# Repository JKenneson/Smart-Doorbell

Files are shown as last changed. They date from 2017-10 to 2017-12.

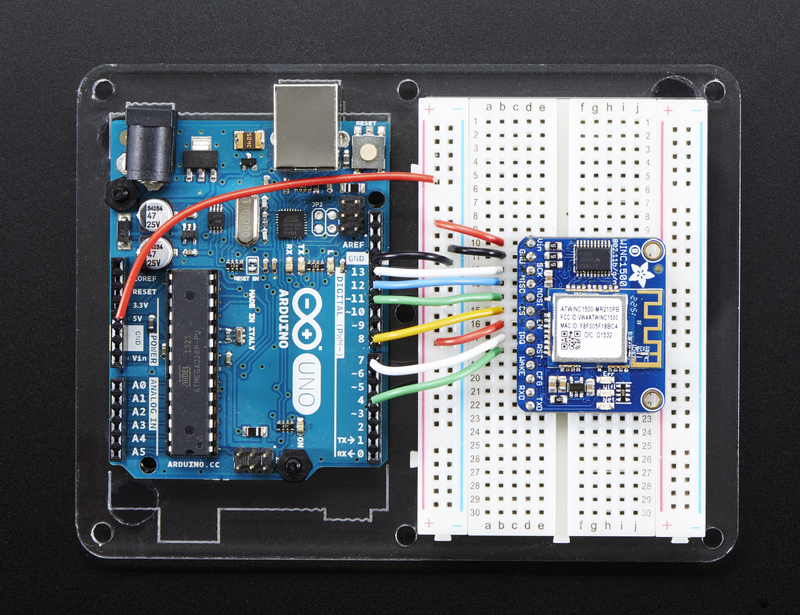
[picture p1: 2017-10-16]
Arduino Testing/Wifi_Test/adafruit_products_2999_top_demo_ORIG.jpg

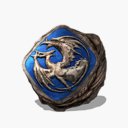
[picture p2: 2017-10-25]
Arduino Testing/Camera_Test/test_jpg.jpg

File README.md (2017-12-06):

# Senior Design ECE 1896
KFM Industries
Jonathan Kenneson, Alexander Furches, and Kyle Monto
Smart Doorbell

The following upper level directories can be found in the current directory:
* Arduino Testing
* Bluemix
* Eagle
* Checkoffs
* Libraries
* Solidworks

Each of the corresponding directories contains parts of the design project needed to recreate the final prototype.

The parts needed to recreate the prototype include:
* Arduino MEGA
* TTL Serial JPEG camera (Adafruit)
* PIR Motion Sensor
* ATWINC1500 Wifi breakout

The Arduino Testing directory contains files related to testing individual components and combinations of components.

The Bluemix directory contains code that can be imported in order to recreate the Node-RED setup associated with the project.

The Checkoff directory contains the code used during the checkoff demonstrations.

The Eagle directory contains all relevant files associated with development of the custom shield placed on top of the Arduino MEGA.

The Libraries directory contains the files associated with the libraries needed to run the Arduino code on the Arduino MEGA.

The Solidworks directory contains all files associated with the development of the 3D enclosure printed to house the final prototype.

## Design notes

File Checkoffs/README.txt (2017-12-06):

This folder contains all our Arduino code for each of the 3 demos during the course of this project.

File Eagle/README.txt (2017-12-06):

This directory contains 3 subdirectories.

Boards - Contains the boards associated with the Arduino Mega and ATmega1284 MCP, and the final shield for the Arduino Mega.

Final Design Folder - Contains design files needed in order to have the custom components professionally printed.

Schematics - Contains the schematics for each of the MCPs examined as well as the Shield schematic that was ultimately choosen.

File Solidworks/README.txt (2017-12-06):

The Solidworks directory contains 2 subdirectories.

Part Files - contains the files that can be view and edited in Solidworks.

STL Files - contains the files that are needed in order to 3D print the components for the final prototype.

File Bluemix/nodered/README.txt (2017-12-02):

Mainflow.json is the only file to be concerned in this directory to get working.

With IBM Cloud/Bluemix, create a Node-RED project.
Within the Node-RED visual editor, copy the entire mainFlow.json text, and select import -> clipboard.
Paste the text into the clipboard and import the flow.

Some things to be concerned with that may require further setup.

Visual recognition node requires API key in order to operate. This can be set up within IBM Cloud by searching for the Visual Recognition service and linking it to the Node-RED project.

The email notification with need an account and password in order to send an email.

Cloudant DB will need permissions adjusted so the database can be read from an unknown user. This is found under Cloudant permissions.

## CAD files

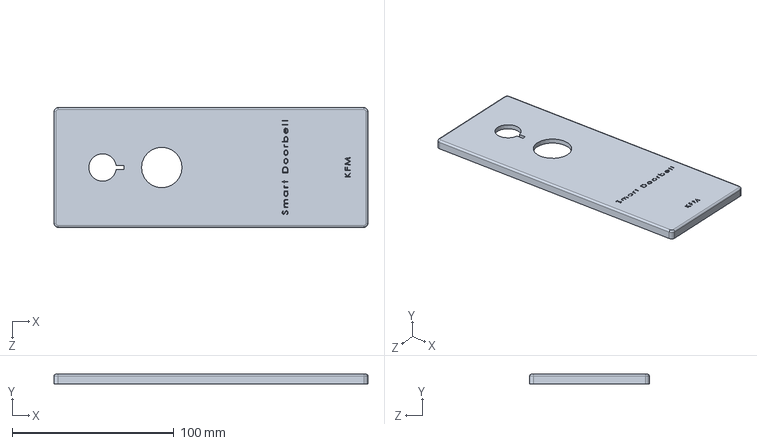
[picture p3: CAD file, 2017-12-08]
Solidworks/Part Files/top_KFM-v2.SLDPRT
194.0 x 6.00 x 74.0 mm

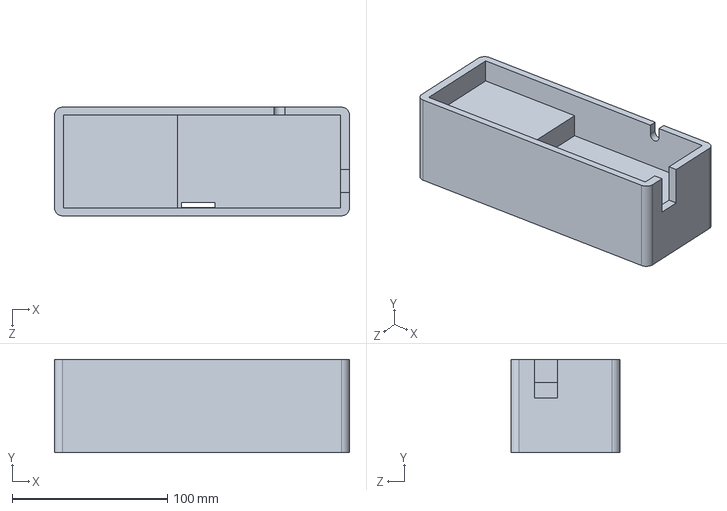
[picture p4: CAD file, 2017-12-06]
Solidworks/Part Files/Bottom_KFM.SLDPRT
190.0 x 60.0 x 70.0 mm

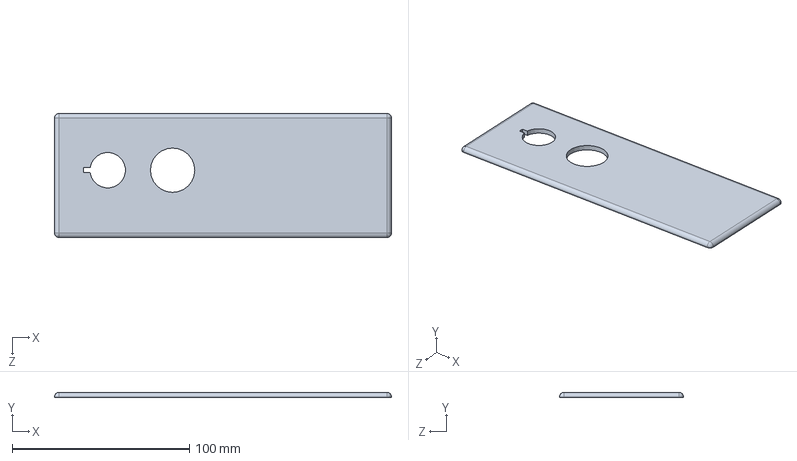
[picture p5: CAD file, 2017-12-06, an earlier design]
Solidworks/Part Files/top_KFM.SLDPRT
190.0 x 3.00 x 70.0 mm

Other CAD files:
Solidworks/STL Files/Bottom_KFM.STL
Solidworks/STL Files/top_KFM-v2.STL
Solidworks/STL Files/top_KFM.STL

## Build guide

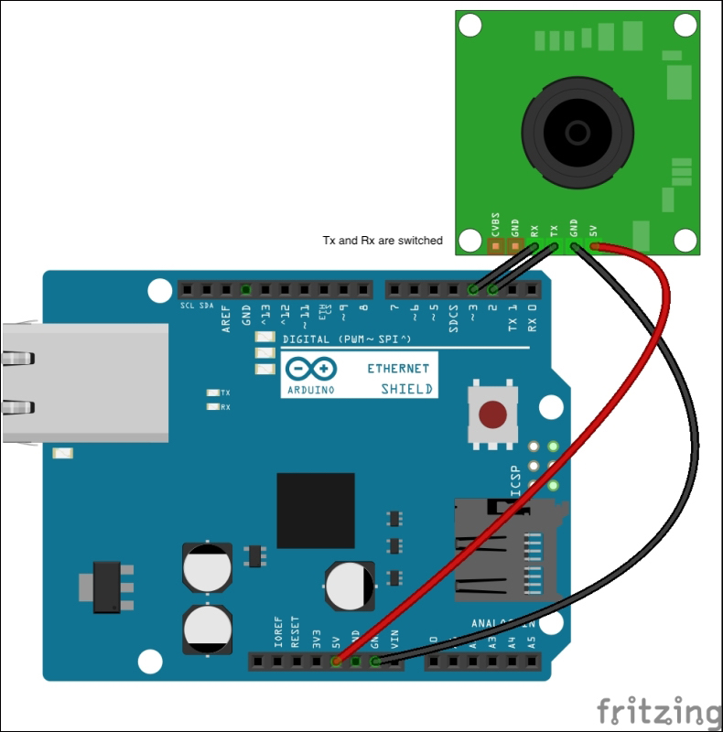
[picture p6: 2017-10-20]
Arduino Testing/Camera_Test/Camera_WIring_reference.jpg

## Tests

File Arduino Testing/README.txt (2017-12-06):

This folder contains all our Arduino testing files for our sub-component testing on the embedded system.

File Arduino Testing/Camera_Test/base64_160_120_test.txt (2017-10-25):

/9j//gAAAAAAAAAAAAAAAAAAAAAAAAAAAAAAAAAAAAA=EgtRBFEEAAAAAAAAAAAAAAAAAAAAAAAAAAAAAAAAAAA=BgYMCQkHCg8NDw8ODQ4OEBIXFBARFhEODhQbFBYYGRo=GhoQExweHBkeFxkaGQEEBQUGBQYMBwcMGREOERkZGRk=GRkZGRkZGRkZGRkZGRkZGRkZGRkZGRkZGRkZGRkZGRk=GRkZGRkZGRkZGRkZGRn//gAAAAAAAAAAAAAAAAAAAAA=IQAAAAAAAAAAAAAAAAAAAAAAAAAAAAAAAAAAAAAAAAA=AwQFBgcICQoLAQAAAAAAAAAAAAAAAAAAAAAAAAAAAAA=BgcICQoLEAAAAAAAAAAAAAAAAAAAAAAAAAAAAAAAAAA=MUEGE1FhByJxFDKBkaEII0KxwRVS0fAkM2JyggkKFhc=GBkaJSYnKCkqNDU2Nzg5OkNERUZHSElKU1RVVldYWVo=Y2RlZmdoaWpzdHV2d3h5eoOEhYaHiImKkpOUlZaXmJk=mqKjpKWmp6ipqrKztLW2t7i5usLDxMXGx8jJytLT1NU=1tfY2drh4uPk5ebn6Onq8fLz9PX29/j5+hEAAAAAAAA=AwQHBQQEAAAAAAAAAAAAAAAAAAAAAAAAAAAAAAAAAAA=QpGhscEJIzNS8BVictEKFiQ04SXxFxgZGiYnKCkqNTY=Nzg5OkNERUZHSElKU1RVVldYWVpjZGVmZ2hpanN0dXY=d3h5eoKDhIWGh4iJipKTlJWWl5iZmqKjpKWmp6ipqrI=s7S1tre4ubrCw8TFxsfIycrS09TV1tfY2dri4+Tl5uc=6Onq8vP09fb3+Pn6/90AAAAAAAAAAAAAAAAAAAAAAAA=z8nHVsjrzShm9cfjXzlnaw+o8Mc8k5qG506G7IMm5JA=fdkQkMv4ikk07jvZnJ+IfBst6vmwt5zqPmcDD465IA8=m/CvPr7TbnT5Atzl16hl6Y/pXTCSkdNOa2IYzgAAAAA=pU6TGMAgllx68iul3Nyys3n8ggJ061DIhTDRsTCeT6g=+lW1fchDfODD5PmUdDTWLqRtbI9Ox+lRZ9TS5ainJGE=mI55JHT8PyroPD9nZ30kn2u/NnMq7lUgkz+wx0H61vQ=VeSTIm2kd5pmpCzYWmnQiBw4yoVHmUj03/uwTj7zKT8=lW5dWEd3A5jma3uolG/yEluZYRjH7+VzhCO67QhHRhw=V7EYqUbdEefJ2Ziwa9aaVIqrAk10gYTXdwVkXGesQB0=o+oJxk8mtj7JfX9ul3c20kMEig29zqFwYEUf3o1O0uM=vvRDjrnNKLlNcsVt/WoPTVmYJtMtL25fXrp9VvJDkSg=kdll9cu3U/nmtC48TCWw8qy05bWJwcTzyrbwFfYnDM0=jt5j/wAAAAAAAAAAAAAAAAAAAAAAAAAAAAAAAAAAAAA=GMa46bQx+Zhg45/LpWSPFtzbknT/AAAAAAAAAAAAAAA=IB9xivKq4mTfu6+f+R1xor7RhTXkrtvkkeUsSWd2zyc=qaYJpOAMkY6g1wScpXbOiOhJvMXzAnb/AAAAAAAAAAA=/t0K6VfSlriJcxMTkyJ7+44/DFctaEpRMa21z0ktgls=kowwwPpUOnStZTfYJGPlkFrZyeq91/D+X0ry2ro50zQ=tzZOGPPvSF2GfmbPbFSnqJhubgEkY9TTgzA9T+dMQ4k=Oc7mJqIv7t9aLCInJzjcc9+etREtn7xI7VVmHQa2Tnk=Pp1qJi2epxj1qrAQSE/3iPx6VWcnP3j71SVkK5//0Ms=DnFSKc8kY+tfNNNIZKD0I9PypwbPUigBwPPvUN5ptlo=tGY9RhDEjh14I/Gi9tik3F3PO/Efw4vdNSS60djfW44=q4xIo9cdD/niuISUb8HKsp5BHI/CuyE+dHXCSkiYSbg=7ovkzyR1zUqS7yAFJYdS3b/61dCel+pViRrZjht2W7g=HT8aTcQpx8oHUd6JXDUYxVPmU8469j9algu5FxjK49Q=7QKV7SuOzaOx0XxPHb2ckM6yTXQG23ljIRQD1DYGXz0=MFgPrxXWi9mvmW21qdYYoPmjs0mWOEA8nYq/Kv4Dr1A=elenSqucfJbnFOFmTQwpdRebZ28lyInP7+Lbb2sRx8o=TK42q3rlRnHWsuTxzBp5kiu0/tTUF+VJUmBgXgYKsQc=djGCOQccNjFa1Kqorm6Exhzu3U5DUfE95fzl5pQgH3I=OIYCDPGPTmsqXUp55N1zM0j9nYli35968adSc27s9CM=CMVoQFmcnfuweDnn9Kch27Q5JX+E1g9SuhKShH86YJA=xYVRgE8EjpU36DYq7gv72TOew5qe0vpNKuorqKUQyRM=Bo3J+4w/z+tKSuQ1eOp9DeCfFtt4s0hLiBlEyfJMgbI=VbH8jW/cQG5h8oEpKp3wuP4GHT8K8iS5ZNHAW7C6N7E=kyAJcRnZKn91h1/+tVvOT1wMVgAAAAAAAAAAAAAAAAA=+uRTGKWGM9TURGMAAAAAAAAAAAAAAAAAAAAAAAAAAAA=849aYTycdKpCK7nOf8KrtnP6mrv2A//Rx1PI54NTK1c=zdnsMkDZI9qcD/8AAAAAAAAAAAAAAAAAAAAAAAAAAAA=cg9RXP8AAAAAAAAAAAAAAAAAAAAAAAAAAAAAAAAAAAA=1LTb3Q7o29/Gyup6EYyPb1qNblWAGdhHQn7wr0076o4=taosxTkYVhk9vf8AAAAAAAAAAAAAAAAAAAAAAAAAAAA=N/r1zQ6+Z82Rx3Jziot1ZY6GTa38TMRxzxWmuqyi2EM=mIndu3lNz/TnIH4DnODxxRzOL0E4ppEN9r13eCP7bcQ=l0Y1xH5jlwo9FHYewqqzyTkM74GOAAAAAAAAAAAAAAA=Ij8wVwFxxwPvU8qvIGMetZdS0+ooL8LkKT0bHWmkDBE=uyeue1KKVgIm1C2s+LmaJPdjyfw61UbWDd/LYWst1n8=i2bV/WrVP7T0RDl0Q6K21S5G2eeKzUdQgLvipF0K2LE=a8kkuWH/AAAAAAAAAAAAAAAAAAAAAAAAAAAAAAAAAAA=LHhL2FQQPL/vgeo6+9fTVndRX1rDcW7q6SIGVgcgg8g=IrzMQrtSOWpHlkNupPsLjUEH7vAS6A7rnh/wz+Vau8E=GQcjt7iuRme4059eT60hPX2pW0EO3EHj8MGmFge/50g=ewxmz9OlRM2O3Iqr9AImf5s9vaoS+Tgnn6U+mhNiJmw=/SoJGGPrVpMZ/9LDDk8//XqRSemf0r5uwyUH3qTJ9qQ=77gODHinZOaNdxjgxzz+lPV2BBU4b1oSAi1bS7HX7fw=jVIlZhkJKFG5Poa8i8VeDLrw6xlKm7sz9yVccfX0NbU=GbjKxvTl0ZzoMifKjCRP7tTRzKpwSxHoRyv+NegndWM=oJ2cEYb8zioHlEXDsCD0z1qLPoAjSyOAAoUep7/SlUM=KcO4ye5oasiiXCdwDjge1KsrIQc49CeM1OrVgbJTLlQ=5PT0+tUpNYtrU7XdS/OMcn/61ChzaIXNYY15e3gxaWQ=wU9HmIWlj0q9u8fbb5kCj5kgXaB/wKm5xpLTVitKRag=dJtLYq0cKs4yQzjeSffNX0mZlwo2Y6j0/AVySlKerZo=K0NhJGPGDubsAAAAAAAAAAAAAAAAAAAAAAAAAAAAAAA=V/s6wlnJHzHYduP97p+te2/DrRdS8PaAlpqh+ZJXMSk=YNsjPIXIPYluK5a8lKHKtzkqtOx1/wAAAAAAAAAAAAA=wEloZLV8mKMgwt/sH+E/Tn9K49epzF3zOM9aTzOSOx4=9HKO4hkx0pN/HPX+VCvYV2xhfJ61E0gB68UNX6BqRGQ=4x+lQmQDuPyqkmDIWlxwDUEj59qtX3Ef/9PnweP/AAA=Tlavm7dSiUP608P6n0qdbDHq+SOcnFShunr/AAAAAAA=jNKpxjBxmmBIPzNP3q6GOZRJE3BVhkGpGcD4m+HwAks=7QAAAAAAAAAAAAAAAAAAAAAAAAAAAAAAAAAAAAAAAAA=uZEflSqAUfj+4f8AAAAAAAAAAAAAAAAAAAAAAAAAAAA=+XlPT0+lBkU/MzZXn2qN7l7aFGXWLe3fZu3nsE+Y0gs=i/vD/o9uIozn55jjH4Vo4qCvMzcm9Iki6TJOwGoXcr4=OSifIp/x7Vet7O2tf+PeEIyjhsZJ+pPNY1KjdktEUoo=W7L0cxckAAAAAAAAAAAAAAAAAAAAAAAAAAAAAAAAAAA=eabpsRC5z9BXT2Hw11q+IeSKO0QgczNjI/3Rk/nWUqg=okymo9Tq9K+GFlHJKNSuZZdjAAAAAAAAAAAAAAAAAAA=7wrpGmNus9OhVz/HIN7H8TmuadTmOSVWUtjeXAIy2PY=UYqQTKpHy5/3uaw1Mr3F8/rzjtgUednnPXrRZAw88js=4zQZT1FSAhm7ZyKabj3pgMabJxng1G0/uKdriImm75o=haXBz1qvJiI3lxnA4x6VSmvYUP7yRQcd2Aq0gR//1OY=g2cEdhTg20k5zXzi1RQ8Mc+1PV6SvuBIHzyacrHIwes=Sab2GSq5PU4NPV/ek7gSBvU4H0p+7PSnZiHrIVbKnHU=rC8TeFbbxFG0keLe/A+WXsx7A/40RbvcqL5Xc8i1bTo=60e6NvqKeU46N/C49Qe9Yl1qVtGNu4M/YAZr04JzSfQ=OttLUrRXN9cE/ZYvJQ9Gk/p3qX+yGZt9/dPJ6op2itE=yUNFqxJOW5ftraC35giUD1xzj69ateYf42x6EYyfYk0=YTcpM0VkiYDeQT+mSa19L8M6rqrKLezmkBH+s27UP/A=I4H61zt21Y+ZR1OtsPhXcSc6nexw85AiXzG9/Qfzrs8=TfAOi2I3G2e8kzndcNwT/ujA/SuSdVy2OeVXsdPbW0c=aII7dI7eMdEiQKB+FWBt7/Mfc5rm3MX3H+bjpkAH0o8=NPXPSiwhRKeaUS8devSiwB5xJ60CfPHcVOiATzsHrQY=fnk/Sqt1Qhpuf7p9e9RG6CdWH0zTsBUl1m2T706fgck=qjL4mtUyFLSfQU1BgZ8/itmOIIgPdjVJ/EV87fKyp/s=oqlFtXCxUn1O7nwHmc/jVJySxLHdVIex/9Xkw+cduO4=amRzkZ5FfPvYY/IPKijcQeCcmp9WMfu+o9jUitwMnvU=PkBIHz9KkRs4zxS6AAAAAAAAAAAAAAAAAAAAAAAAAAA=TxZoX/CSaTJaBYTIeVaUElf90joffp6ivGLnQ/7CuXg=J7VoZh3I6++a7KM5Wcbm9K3UQbjgqdp7470+KMuQAp0=x/EmtLrudPqbln4R1a8HmpZyRxHBLSjaB7jPJH0Fdlo=Z8NYRtbU7xpz/dgHB/Fh/SsKlVLYxlO2iOx0vwzpel4=02llErqch5B5j/mc4/CtxQOMktjsa4m7u7Odtt6kyuA=YA4+lPEp/Oo9RD/MwPrS+b2B6UgAAAAAAAAAAAAAAAA=mwAAAAAAAAAAAAAAAAAAAAAAAAAAAAAAAAAAAAAAAAA=G4FGXxRbqMRB5D6jiqEvii4YfuYlUf7RzT5bDRVl1u8=ZT/rtnH8IHFU2nmmb95I7E+rVVuoC+WTzn8M00rtP9M=NSw1AgdlApAD/hTSuAh9M/rSYHrg0X8wsf/W4wHmno8=XzzRWrJkkUDB5p4fI6elK3UBwIH3eR06U5W4xxk+9TY=QWuPV+hPpUoccA8f0padAAAAAAAAAAAAAAAAAAAAAAA=nbgPr9aiyGODjPOKo6rpFlrUPl38KvgEK+PmX6Gr03Y=NNp3Rz9n8ObCA77i6mucH5U4Tj3PJP4YrptO0aw04D4=yW0UJH8SjLf99HmiU3ItzcjUBUdQGPvzUnm9cVloZjw=SjHXrTllNLTsMcJxjJqTzgOdwqeW+4eQvnjqelHnYIA=Tyew7UWsIjkvY4xmSQKvqTjFUJvEVnFnEgc5/gAAAAA=luFim/ipcYhhJHTLHFUZ/EN5McIyxA/3RzTUF1HYoyU=zPMf3srsfc0zAAAAAAAAAAAAAAAAAAAAAAAAAAAAAAA=XHApwxzxRbsSvMnGMZ6464prjdg0mkihnTGMdqTAwMg=6dahJXuID244pucHB9P1qrKwH//X4UOT1yc07cepr54=eqKHByelSJKfWlqwJhJnB747U/du9SfSjUVx4YLjJpw=HxSd1LQZKrZ6GpFf0OKnW4Dlc5GeKeHOOBz9aT3sMcI=Qg9+KcHwfU0t9wQokIHNPWTsT+dTZ2FsOEpyM5/OniU=zjPH407Nbj3AS9ad5xB5P60WBEcuoRRD97Ko78sOapw=viG3ThGaQ+wqVe6ApS+JJTxDF16Fj0qpJrF7P1lKj/Y=eMVXUZVZnkOXZmPueaBnJGOnNGq2D1JQPlzyTQAAAAA=LPoO4/HPp75p4Byev50aoOuo5Rk4ORT/AAAAAAAAAAA=kEYz60uCTgE5obfUCdfT9aV147n2qW2kwTIiPmOOn0o=MnvmnrsIaeetIRjp/wAAAAAAAAAAAAAAAAAAAAAAAAA=Ch+nXrUobA4OaN0MVXGPf1qQSYHB6UvQB6ze/wAAAAA=fT2o1YEkcvIxnIqQS84NS7sBwcAjk0vmc5559anVgL4=bg07z8kUPuMXzsE5yeOlOEp/h5PtRoF2Ne7SHAmdVzk=6nFVn1y3H3SzkdlFK1h2KcmvSvjyYgvuxzVObULqUYc=lZfYcVVhkPB5znPX3qRcDHyjBp9BddSRgM9OfWkHJpM=tsPqKDinjHTPFTbcW5KMFeP6UmcY4HSjW4x2cn5uM80=OBB/Op1YWHA8ipM8Dr1qeoDgQRzzn2pw6exoYIeG28o=45/SjOeOhqdkHUOQPWjqQT+NCeobCHg+1NPAAAAAAAA=IWh//9Hzs9OP5UZwf/rV4Aw3n2/wpQ5JoAUSU8Sc9f0=KEMcJD+VSCY9emetLTcCRJ8n/wAAAAAAAAAAAAAAAAA=2DjAxS+ccHngijZiENyqAAAAAAAAAAAAAAAAAAAAAAA=DIDrMjZ8mIKB/E1V5NRupGIMxUc528CmrD9SIEsQWww=fU8mpQMjmiyARnJ4HalU5PGOKmQDs/TpTg3uAcelDEM=jJ0OaXdjk4pPuMXdxk07JHTFLugJEyfpj0oB5zjoalM=6jH7iD2xSh+ffH1xQvMH5Ds8gmpM9MdT7VPqHoODdeA=U4Mx69KHoA8ZBxnrSjIz398VLWlxvYceh78UufoKTFs=jWJ78U3NV2JP/9LzluPfFNLEYzXzyV9UUM39+cUxpsE=64z1p2uh2Dz9p5IxS/aBnngj6UW0sJD/AAAAAAAAAAA=4BFJoe47ztoDZ/GkbUYk6yDI7A5os3uJEb6uv/LNGY8=vVd9RuG5VwgI6Cq5bvUexCCZWHmMXJ9TmpQuCMnp3xQ=mh7jieeCTjoBSqvPTpSCxIp54Jx6VJu4Xtmk13FuIG4=flPPal3gkAknPWp5Rjg3GT2pQeetFnbYBS/PNLuwQKU=qgHZznv/AAAAAAAAAAAAAAAAAAAAAAAAAAAAAAAAAAA=0A4PvQwtYkzkc8mn5x7Gly2AcTnr0pQ2OR17UNDJA3M=gnrS7j0zkjjpU2dhC5A5J59BS7uT9OKTXYBoPTOBSZ4=vemkybn/0+EkjVu3WqskRGSOfwr5/qOxVfcM57CqzSk=HGTkelWrN6DIzLz7d6YblFPzSYOPXNVygQtqAU4jBJo=a19OxyvyA+gp8qWrERGVnb52LEepqaHliSSeKqySsMk=P4snqc0/uPes3uPoTxthu+AD1p+7aQG/Kp07j1Hgnj0=u+aUNz39eaNtgsiSNTIVGVGe5PtSlu1RuxiA+hOaX0w=d6G0tWKw4enPWnKcgAdBSe24AAAAAAAAAAAAAAAAAAA=rA9sE1IuKTDQlzletA6D+lTa4DgckegpQe/NDsCJR24=9OXJHGTikLcfz16U4NznJyOvvSe40Ozkd/bNLuORjH4=BoukDQHp83UcUuSOp5pIQnf1Hb3oyT06+9O6Qj//1OE=T2qNugNfPFENwVKOzDJUE9K5ya6bd8vy89xWkBoqtJI=SdSxFR8DIrZa6C3F28j3x9ambGcentUrQegqL8w9fpU=YiXHQnAxUtu4aEhOKev3h1HbgVG+49iVCMkjC08+p44=f8mkPQUN6kD8KeDg5NLcNhwbGBnrTgcn5vpU2ewaCjI=zDIGPWncbsDp60nZqwPcAAAAAAAAAAAAAAAAAAAAAAA=9qQH5v8AAAAAAAAAAAAAAAAAAAAAAAAAAAAAAAAAAAA=JBg47/hQOCO9G4iQdPTPQVZQZQHIqHoNCk8YPX3FR4E=njBBpvQQ8cZ6AAAAAAAAAAAAAAAAAAAAAAAAAAAAAAA=wM4I/Wmknv1+lGiEf//V4Vh2HFRMeDjrXz9iilqLlLY=bHf5a5w4xn1rWCurCI93IKtg/wAAAAAAAAAAAAAAAAA=Mke/Sps2h7D4yeucVMGJ4XAH86loPMfnptp6dSDx3+k=U2Y9CZT03Dpk0rNk5zkg0noAAAAAAAAAAAAAAAAAAAA=ucdeP8KVSWIBIqrCQ7ITGTknp7UoPOWBGe2KzSvoMUY=fTGewNPBzj9adtAuLyCD27U7gHqck4okmK44Z59KkVQ=55POMYzSaurgh+D6Ae9AwMc/kahAPUqDz1p4If5h96k=WYXHg9On4VKmd309qXQBz5HTJ9/ShTk+4/Whx7BsO3c=TIyAc+1Lnoc8/WoYApH446gdKXdg5pvcAAAAAAAAAAA=8U7NiP/W+YtE+LN/bsI9agW7jx/rIxtcfXsa9B0jxho=Trij7HdKJP8AAAAAAAAAAAAAAAAAAAAAAAAAAAAAAAA=BnLEnFYRcgHtXPTTsMMjPH8utPHOB+VWwQ8EgAfzFLw=YHGTU6vVDZKoweMVIHAwB0PepAkz8oOKco6kA9anmaY=OxIDnnHH1pd2DwTn196QMcp6Y44x0Oak28ZTljz16Uk=3GLnAAAAAAAAAAAAAAAAAAAAAAAAAAAAAAAAAAAAAAA=O1S7TxxSeu4rjgmeMfjS7T3Io1YIkAGPm6U7ljlQRzw=mk+4aigEdQAAAAAAAAAAAAAAAAAAAAAAAAAAAAAAAAA=F6VLEAAAAAAAAAAAAAAAAAAAAAAAAAAAAAAAAAAAAAA=7QOvpU2sAZ7YpeBwKW+oC4zwTgAAAAAAAAAAAAAAAAA=1/hvbk+vPrSbyuCOMCtCbnrlqbmx0jSbe8kaSc2qzSA=Ykld+WA/BSv45q5HKSOvBryHFXbRZNuPpzjripFIOM8=b61nZjuTKRnp24ApSeRgDA71NgZIvGMjn1FPXHG7Oag=t1K6ErABlBGOMmlBBO4ckUW1AkXnt14FLkc+tFkwV7A=8cH5Tj2zUgAAAAAAAAAAAAAAAAAAAAAAAAAAAAAAAAA=KANuf1pdoLAY5ApPcAHHvUowduDU21AfnjFKPekCHBc=J5BJqXB2jJ4AAAAAAAAAAAAAAAAAAAAAAAAAAAAAAAA=YUMwwM9KT5SeF49fWps72H0HKo6BufbvTxkHvnpiizQ=A/G/g5z29aAAAAAAAAAAAAAAAAAAAAAAAAAAAAAAAAA=HAJ56mlYY8DcMlQfeg4wc9PXNDsgEIy34UhUMc45pBc=P//Q+G85PpVrS7I6nqljZoM/abiOHHszAAAAAAAAAAA=5634gmE2sXDJgIHIUegHA/lVeB+x6ivIS93QvUso3QA=xzVlfc1LAlDY5PQ1IOnTB9qzdtxjsnGMk+pFSoAfT/E=paXK1HsMvtHBzj2p+QTjJwOnPap13EPAxkkc96VThsk=bIAwM0rJjbZIDjIPH071LkAcDqMYqWugIVc4AXgdsU8=U5JyfT8am3VjYvJPH8v8+tLjA4HaktULYULwP84p65w=gdKVtbgOxg+pPGKl2HqSKegXHjGKeV4J9e9Q7pj3FUE=HfHpUyJgEnPHUmi+twAAAAAAAAAAAAAAAAAAAAAAAAA=KhJ4OAfUmpdthbjgMAH1pT5ZIycNn0JprQAAAAAAAAA=KmjHT5gMf3s1DvsO409eufWnA8k44pvQWopw33STz3E=SEZ+uKXmB//R+HScdORXXfDWzFx4vspCuVtEkuT/AAA=VIH6sv5U6rtSbJudPdPvnY88+wqWBcZ5xjvXnWaRZag=+Mf1qZSO56DFZNaBcmGeMZyPyqQDB569MVD1GmPB6Dc=d8ip4gMAAAAAAAAAAAAAAAAAAAAAAAAAAAAAAAAAAAA=HBPrT1UZ60nHqO48cn+lSDqB6CpsCeg8ZwMjJHtTxyc=19j1o2F10F5J46gZp+MYyKTQXAqc/rxT1BPTHXpSYEw=mCck4Prinsq8fMc9frQwv1HADr19qM8j/Ck0ugXZJuI=v3fTjNO27+OQPapadguAiHc5+hp4TPUc/rQDFC4HGeY=pMY7dqNG7hsPK4HY49qaoOeOce+KljuOO3dkjB/L/wA=10pG4bWJHf2NK/RkhsPbJ9hQAVHPb34NK1yrihSenYc=pTcZ75P0zVepJ//S+HMfN9K9G+F9uVh8Q3+3BitkgRs=3ckn/wAAAAAAAAAAAAAAAAAAAAAAAAAAAAAAAAAAAAA=NpGamGMLnnJ/OsmMkAbI/TB6cU89MKOKlruMl54PYZ4=lTISSCTzj1zipaH0AYIAAAAAAAAAAAAAAAAAAAAAAAA=c44HTigDBqFtcp7WJFXn8MVIoPQDPOaRLRIFO/oTTvQ=7d8HrSaYh2MEEjk0qqSBu4HpU7sOg4JwMjIxUir9Bik=2C47aO3PepFBB4OQe/el6gOUY4x3p55Prmp2Eh4XAAA=pQp4yDjPFNb7jH+WSD+dSLCeCRj6mp22AUwnAwccetM=hD2Oc+wpO4JilBjAB6UjR4YjselCVtwYuwdxuApyoCM=CnH9P8RSS6CuNJ6FjuFLgEdDnORzR13C3cTaSfkGV78=NKFGflQdORmqVkB//9P4cwMkjtXq/giH7L4Du5sAAAA=pYz6qiKP57qzxDSjZ9xDSrbwDn6VbjHp+tccrFIlXt0=W69O1WCDgk81k7XsMcp45BzUgBJB6k9RUNXAk6MQOnM=TwTsXgY9aWjAlQAAAAAAAAAAAAAAAAAAAAAAAAAAAAA=MAZII+tZtItu48EtjA5xycVIAQp9QM9KTSuZkijJ6fU=FSqp5+XIx2qXuFxSOhIx9KUDGODRbTQPMft6EA+xqQA=9BzRv0AdtGM/hTwD1xmk/QNx4AHQHFSKoJ4HNLW2wMc=rz0/DvUypzkdDStYCdFAUEjgnPtxSlctwc+5PalZLoI=F3sDwOcdF6CgfMPvHPQgEcf4UNAOLBTk5Oe3HFRkbwA=jjjtSasO6FG5enFLuYgFlAI9Bg0rWQgKh/mIx6c0nkk=BBTnJ49qejGPbKAFkD+oU8j/AAAAAAAAAAAAAAAAAAA=Qk//1PiF4mjnaJgQ6uVYZ6EHB/lXsOnQi18B+H4SMGY=jkuGH++5I/QiscRZxVu4kUUQM5PTr0NWlUg+2K5Jdho=JowBgdPwqV+vTgelZNLYpaDhkHOealQHdknNLcB4HPI=cjNPK5UY7ZzS0QEoBA4J9KmjBI3AE9KzshkihmPU89I=ngdjx6GlpfQpN2HqBkYwBj1qdY2YLuIB6471PUWxNGg=cnJx3z71IApz6DjrU7O4MXHccemTSiPOOePr1o02Adg=AAAAAAAAAAAAAAAAAAAAAAAAAAAAAAAAAAAAAAAAAAA=HuKlVQAAAAAAAAAAAAAAAAAAAAAAAAAAAAAAAAAAAAA=La7EIV3AckYHOaFjKc7h+dLmjYdiYR5GW5z9KnSBSq4=4YAGA2cmiyFe5HJAAAAAAAAAAAAAAAAAAAAAAAAAAAA=DHgHLYxjj0pNjGFMEdDxxmkJHGXC89duSDUhsMHyHhs=vzxSFAFGGJ+tN6Af/9X4z8RBIvEmrm3O5FupWXHrkk8=65Fewa/b/YrfS7IAAAAAAAAAAAAAAAAAAAAAAAAAAAA=0DIyMVYGMBcgkDnnvXLJa6FEoG0j2FP5yRwKzshokRQ=nHIJ7U8E4xxxn8aWjAkHbP16VJ12gAZA4FJgSom4jHY=/SpyRgAAAAAAAAAAAAAAAAAAAAAAAAAAAAAAAAAAAAA=wpOKY0+hLuyyhTtIPGMfWpkjZy2HULnGT61HKl0C5MA=IkhCMzEDGTgZ/D8aco2r8ozjv60mAqje5UAkhdx+lTE=BOQCoUH16+9TyoBwjBGBgAfX+tSBMHDDH0Oabitwv2E=5XBGMCpI1LHrwB6UraATKh4256/Spwir1INLlQIeMyk=yR1PQAAAAAAAAAAAAAAAAAAAAAAAAAAAAAAAAAAAAAA=dGT0xtIpWtuNaDlQ5wMD8OaeUPO4YPTGOKLMVxQAAAA=g9DTXjwRjPtSsCEUj6j600jPIUpg8UJaCIiuT8wH4HM=mlJO0qvANKw9SNV5xkYI5BpNgjO0AYI9cUn6Bsf/1vg=x0e2bUtasbdvmN1dRxse53OAf517F4um8zWLgjkDAAA=Q/xrjrr30hIxIvvY/M1YGTjH/wAAAAAAAAAAAAAAAAA=HIzj15xxWTixskTJIzTsc8duBStbYCVOMEc+1PB+bJ4=nWps3sMnTODg/lT1UEjpzmpcWIlC4YccEZx1p3KbiuQ=5IyT+NK24ydFYFicAZ46e/X9KsIcIQAAAAAAAAAAAAA=5z0p4HHPBNJphcmXcIXG5VR2xt/iYDHJ9uB+tIg3MMw=bheTxxmm0xE20AcDH4g04JycD9aWwyVUIKAjg/pV2O0=x0VuO5IxS5WtRXJSoXpx12A9T7nFSRQZTseAM1OvUNg=f5Y6jGfrThHyNnTv60WfQL9SRXcY2Rb1HXBHP51IYyc=g5z70WuA7y+enFOEQUYJHsfT2NDWghDCQexB6c05oiA=c9/zqbdgIjDkDbz7U1o9nUEnHNO2gbkbIGxsH0Oc/hQ=1o2AOQQoHTj86nYaImjXnb0AAAAAAAAAAAAAAAAAAAA=/9f5P+HNr9r8Z6Su35Y3eY8/3EY/zxXc6y5k1C5cnkw=rY755NclfWol5ElGJGPHP9KmUYJBHTjg1z2ZdyXk4B4=M1IgGQRwPXNQ7jRLj5uARTlGTnGSe9FmIlUsOSeh/Ok=4AyADketTqBaCMYS3AHWpFTHTJI/TpUa3KTHKQmRklg=/e9/r+VSoGYjnHGOah+gEqg5IznOe/X1qfGF+Y8daNQ=BQOe/Xp0qQLnkkrjvms13DYeASejN35H+NSDcOgIx/s=VFu4XJlHp0xUkaFj/nApO97gyZlG8Hrg5Yj1q5Buk24=4kkDPsPpSabQFgQsQAcMW7Kc5/HvUqx+obg9ux+lK7s=h6jo42ZR8wJHGRUyxFiM5/w5zQrivYmSEqfr14BqQwE=XHelqguIsOWxUskeRxnHQE9cUmFxgiY5HAwOmaSRCwA=M8gdSe1DsBGFKjCuQ3sDUGxs88ntk0ILkchk5DE8Z4I=OlRAsrfJwexqbO4DWLOvJAIbIIH3fbHpUTgjqu1gcEY=OlOwj//Q+Z/g9AZPE88/H7ixds+m50X/AAAAAAAAAAA=/OS3J5Gea4qv8W4rXGwvtwNuOc5PoOlSxnc3PrzzWeo=itCZTzxxipF5OcYrK1gH54H9aerZGMY96LXHZEidGI4=fpUqjGCOme1TZoRe2/u0A+XJ59qOeiYIx/8AAAAAAAA=gU9uKmzyw7k9cVLTB6k4AAAAAAAAAAAAAAAAAAAAAAA=FzhUUY7DOKkVAuCcdeM0ugaE20cEkkk8dcUu35sY5oU=cRMq/KCVOM447mpgCSFfgE88Z+n+c1LViiZEC8Y79O0=+VW41YfXpzmhqxBZSLruC9OeTz7Vbji4w2M/3f8AAAA=+lRJu1hokEG8/wAAAAAAAAAAAAAAAAAAAAAAAAAAAAA=3oM5z1B/z/KnLGT1H0x3qAFMC7ccfnjP+fWhYMjqPfg=pANaJU6445Heq0ibz0x9RTTGIYVHIGfwqCRFO4kY47U=NXBFRgAAAAAAAAAAAAAAAAAAAAAAAAAAAAAAAAAAAAA=/9H53+D8SpB4kumBwlvFGMdQf3jY/QVYuAN5wMMK4qk=/EYkNVc7iAeBUqAc44rOTKJ0AAAAAAAAAAAAAAAAAAA=GN3QnHapF4PTArNsZOgHK475PNTKoIUcnPXnpUttMaI=+wGOMAZH6dKYR1wODUXsPckTGAS/cYGckU4JtJJ+6B8=lSuxFlE2jBXJPWpsblzkAYyByePU1DeugEkSMTx97GQ=9sYqVI8ouMDv1p3shbsdGmCOSeOM1Mi/NlwAAAAAAAA=3HoToBgAAAAAAAAAAAAAAAAAAAAAAAAAAAAAAAAAAAA=xnBXGKvRw8ANmpZDLsCbshMdevQ1aS2O8kpjAAAAAAA=9aTd9AJ1tMgbufXFWEtsEBcH19qhyvoBaitHWF2RS0c=kbvQE9/88fplrW/Hyik2BGYWA5HtToLfzAFUDjGcnFA=3dXAhltiHIPXJHFQmEA9cjNK7sA1k28beR+dVJoV2tg=JJ9aaeoFF1AGELbemN1VnXJ5zk1d+oEXIG1j8pPHr/k=60ySLYTgDkAjn/P1p76gf//S8B+F8Pk+C/EE2DmS4EY=D64jX+slNmO5ie2a4Kv8RsFYWMd9nPSnqCWGPX0rFa0=7jsTZHQZzxzU2MDAHQUXdhIOhx/WnAAAAAAAAAAAAAA=HbP0qwU2OVyMqOMUC0LMZGAp7dakC7tqgbien41i1bU=GTYxhM5weT/n0pQuT6DqfaiyC5YUbuOh7e1T+UpPoWM=n6en6UtbCJEXByCBnr3/AAAAAAAAAAAAAAAAAAAAAAA=tR3Q5V6MyHnp1GakWPcQFbgdh2/SoSvqDsTCMJnaTwc=rjFWIYiwA3Db0AOST3/zmntqw6mjaQYfjjPU/wAAAAA=IlDBQgAAAAAAAAAAAAAAAAAAAAAAAAAAAAAAAAAAAAA=OxPJz/8AAAAAAAAAAAAAAAAAAAAAAAAAAAAAAAAAAAA=G4IpK5ZCuW74B9fX/Dhn2R2JIzUoBps84GM/hUQ05iw=VUqseMEbcHP1o1QENxp7+Y3zgtnowwfzqnNaNGeemeM=nOKtMCrNEdvUD2qjLGVGSSAetUguim8ZGOahZBkfWrc=ECtNF5ZPGCP0703GV2sMEd6aWugH/9PwjwHmD4bXLcA=abUZM4HXhF/9lqnIcsdoGBnOBXB/y8kGhKgAAAAAAAA=pI1ycDH3cnis5DWpMg/SnEYY4x7VPUelhyjjtnHTFSo=Aq/BBz0461MkBZRWBGFIFSEnzHZx8+cmpAliUlsAAAA=31q/5RiH8LSZ644FTdLcY1QTy2OnccVIuVGOM96jSTA=ejJUToMfpVlVwu449qGJEyqDjjGBknrU6EMpyOuQMjg=4H/1/wAAAAAAAAAAAAAAAAAAAAAAAAAAAAAAAAAAAAA=HHU45NPTZC0FERYjgc9KvWtvM5VIEj3v8o3L0z79qmQ=tLAaX2fy2CK3mAAAAAAAAAAAAAAAAAAAAAAAAAAAAAA=mrDanHyDnHPGK17WwcoAAAAAAAAAAAAAAAAAAAAAAAA=Cp9Ov8qsR6S8jBVQ5bOOOMev0rF3DQsS2SlY4o0wka8=JP8AAAAAAAAAAAAAAAAAAAAAAAAAAAAAAAAAAAAAAAA=7A8n8KznhjRtu0sD6g8/hTUri0uVJo8jOwIDxk54rJs=pNuVJJA9+P5Va0K9DLnG0YC4IP5VnygkEnAJrZC2KUg=vHH54qrKuQAAAAAAAAAAAAAAAAAAAAAAAAAAAAAAAAA=lBzx9KYaH//U8H8MTxR/DSyUugdr2ZmUuNwAAAAAAAA=s83MTfdmj64HziuKcJKck0OKurrUmE8W0ZljxntItTQ=VxBuB86H3/eLj+dZSh2RSjLsSLcwk586LBOP9YKeZ4A=E5mi9f8AAAAAAAAAAAAAAAAAAAAAAAAAAAAAAAAAAAA=fOhHqfMX/GlaV72Dkl2Lcc9uxB8+Acc4kXr+ftUguoc=Dn7RAAAAAAAAAAAAAAAAAAAAAAAAAAAAAAAAAAAAAAA=enHekN/bSYJuIRu4H7wD9M0uV22K9nPsyRbq2zn7TCM=Gf8AAAAAAAAAAAAAAAAAAAAAAAAAAAAAAAAAAAAAAAA=wf8AAAAAAAAAAAAAAAAAAAAAAAAAAAAAAAAAAAAAAAA=idpurfHBP71f8atw3FqFXN1bqCDtzMvTP1+tO0lug9k=Ttsy9Bd2wfY1zbLhiDunUdO3WrAvbNMD7TC7DJwsyhQ=Dkc89M9/UfhUunJvYnknZaFm2uLJx+8vLUH2mT19zWk=xXdiHHlXdsoHBJuEBOR9fSocZbWK9jV/lf3F+3ms2dc=deWgzwuJ0/lnmti2nsh/y+2nB/5+U/xrCUX2GqFX+V8=3M2raSwDAfbrMEn/AAAAAAAAAAAAAAAAAAAAAAAAAAA=3GOvua5paLUf1et/I/uZqwrp2CTqWnnj/n7i5/8AAAA=1k008nUbDaeD/pkXT/vqubnQvq9X+R/cyQPpxxjUtPw=en2yL/4qhpdNUMf7S0//AAAAAAAAAAAAAAAAAAAAAAA=bTZkEj6lYB9m5XF5GCw/un5s/n7Vlz3ViST/AAAAAAA=pcRjg+uWrRNX0D6vWf2H9zMuS5slJzfWQU8E/akP6A4=axLu+snP/H1Zr2wLtCD+bV0RUpbIHh6y+w/uZl3N3ZA=UkX1njpxcJ/jWZLe2meL21x/18J/jWyjL+Un2FX+V/c=Mpy3loORe2uRj/lunX86rPfWrAj7XaFWwcCdOMdxz9c=/JrTll2D2FX+V/cVpry1T5Td26uCQwM6ZBBIx1qJLy0=xujW6ti3bEyHP4ZqlGS+yHsaj+y/uP/Z

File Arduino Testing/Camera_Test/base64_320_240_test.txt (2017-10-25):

/9j//gAAAAAAAAAAAAAAAAAAAAAAAAAAAAAAAAAAAAA=EgtRBFEEAAAAAAAAAAAAAAAAAAAAAAAAAAAAAAAAAAA=BgYNCQoICw8OEBAPDg8PERMYFRESFxIPDxUdFhcZGhs=HBsQFB4gHhsgGBsbGgEFBQUGBgYMBwcMGhIPEhoaGho=GhoaGhoaGhoaGhoaGhoaGhoaGhoaGhoaGhoaGhoaGho=GhoaGhoaGhoaGhoaGhr//gAAAAAAAAAAAAAAAAAAAAA=IQAAAAAAAAAAAAAAAAAAAAAAAAAAAAAAAAAAAAAAAAA=AwQFBgcICQoLAQAAAAAAAAAAAAAAAAAAAAAAAAAAAAA=BgcICQoLEAAAAAAAAAAAAAAAAAAAAAAAAAAAAAAAAAA=MUEGE1FhByJxFDKBkaEII0KxwRVS0fAkM2JyggkKFhc=GBkaJSYnKCkqNDU2Nzg5OkNERUZHSElKU1RVVldYWVo=Y2RlZmdoaWpzdHV2d3h5eoOEhYaHiImKkpOUlZaXmJk=mqKjpKWmp6ipqrKztLW2t7i5usLDxMXGx8jJytLT1NU=1tfY2drh4uPk5ebn6Onq8fLz9PX29/j5+hEAAAAAAAA=AwQHBQQEAAAAAAAAAAAAAAAAAAAAAAAAAAAAAAAAAAA=QpGhscEJIzNS8BVictEKFiQ04SXxFxgZGiYnKCkqNTY=Nzg5OkNERUZHSElKU1RVVldYWVpjZGVmZ2hpanN0dXY=d3h5eoKDhIWGh4iJipKTlJWWl5iZmqKjpKWmp6ipqrI=s7S1tre4ubrCw8TFxsfIycrS09TV1tfY2dri4+Tl5uc=6Onq8vP09fb3+Pn6/90AAAAAAAAAAAAAAAAAAAAAAAA=zwc45NKpOfvHGfWvCaQ7km4+pqG506G8A89SHHRkYqw=v0IpK6YeZzHiHwhLfoXiInlXow4fHqezfoa84v8AAAA=051EvzxkZDJk/nXRCSOinLTlIEIxjqD+OKmSR48spBU=PvyK2hpobMtibzcgFVTuSf51C8RUloj8nXnj8verXmw=laDRKOBGN3qfQ0jeYGDI2SeozxU2ZdyxFO3HzkdvT9I=t7QrS01C5ZLvUBaMELK7DO89lGOK0pK8kpPQibtG6O8=NPu4NLJtrO3jik43GRPNft82GwvJ6GTOM10V1Yrfwts=nlivwnmKgEl3dJ1OXIAWMc/wIVx6c160FdW6HFK61Zg=iaraaPPGjxJd3qO2+4nKyRBcYysakqW9ecj8OddILvU=m0W8NnNLYuD5M13P5FvyeqZKiQj0UORipg21yw/r/gA=PTWRQdrC21CSTxJqb6hcFMJJHM8oPbaWbB9B+mKvp4k=lFkY9J0rykIK+czpBEox0dzyTxkYkXP93tSUoQut33A=alJeRxs/i+60SYxWOpu0TcN9lYhU56BzyR9OO3IrFHg=rnt3L2SQRyAk+Y8YlYn1+YYz74zXn1MS72i7nTGimjE=LrUbieV5p5ZJndsuXYnn1qITSjgZI9e1ccm5O7Z0JJI=siT5o8OOn8Q9q9a+GHjEyBdIvZiWVc2756j+7+FctZM=lFmVVXjdHqhbDBwcjv7ioLKY2FwLQkiCYlrZs9D1Kf0=R+VcDjc57mluYHrz9aCzAnk5z60egCZb1IH1pwJ5+Y8=rnNJdAHsfVjmo2Oc8n35otcVyJy2CM/rUOWB6mqtoF8=Uad3QN+tRHPYmmlYNCGTJx8x4qs+c53H86pabiP/0Mw=VhUgIwT+teEmMkDelPBweev0pdNQHZ5yBz2qG7sLLVE=PL1KBXGMbx94UXaeg07anAeI/hrd2iyXmhMbmAfMYyM=EgH8iPyP1rg/M2uySZSRfvBhgj8K6qc+ZeZ1QnzEok0=+Gi4JPJ9alWYOQuCWz0Pb6VupKw2raD3ty3zBgG9AAA=SAnldu3HUGkxoVivLKccdc9PrmlhuXzhMg+o4x7g9aU=zWd0FrnX6B4pgs4HS9WSSYLm3khPllGPBywG4/TIHr4=ldfFqN1eQC01SVbW3CCYWsUqxxSZH3tq8Z4GT94dyes=Xo0avPHlOWpDldyzBbQagzpY2kt2IWBYWy4jjHrJMwA=ARx8xUj3rPn8aQaVNJDrAAAAAAAAAAAAAAAAAAAAAAA=ZGOmO2k6sacb/wAAAAAAAAAAAAAAAAAAAAAAAAAAAAA=A/Sse51W5upi11M8jkYDuxY/rXlVKsqj12OuNNRKxkY=kcliSD/ezz+FKrBCN5LL2wOhrI0sWCy/3R+NRo3lH90=qdp6EjpUc2mwWSDc2CJZBkdAOv5VLBctp8qTxSGModw=j7sbGByDRJ6bEtJqzPoDwB4zg8V6YSCou7chJ1U55xw=MPY11U0K3MLQOdoY5Rx1Rh0IrzakVBtHIlqT2Fy1zG0=HcgJdQnZMo9fUex61dzyf7vesmtWAoTIBJA+ppDgH18=pSvYQ4NxwMnmoGOPrVLYOozvg9OtMY5ySOvrR5CI278=aomPPI/GmgIJCDnFVnrRO4H/0cdcdzxUyue3T6V4YyQ=Vgc9KfnPXrUt6WAcDg8jrTw/fNS7jJorl4jmM/UetYs=4j8G6d4ojaSJVt9QAyHUcH6inFuLuOMrM8c1jSL/AAA=101tqCHIPBPceoNVlugy7fu46E9RXdCXNZo6r3RZiuM=acSAHgkN2pZWLk5wqjoM/MPw7VpezuCvYjyEbOBv7MQ=5FK5MgGevqalp7lLUdG5LEEkk5xzwa1I9VmS3eFjGWY=PDtlnQe2eB9cZoVRrYTimiK81+8uo4oL65mljh/1UTM=Eon+6vRfwFUzJJcAAAAAAAAAAAAAAAAAAAAAAAAAAAA=O9SELkfKp49KylKxSV9w8yRTsOFyOGocDBR2znrSb7A=+hC97DacXUsaL/eY8kf41WbW0uTss7ea6J4G1cCqUG8=V7Et9BIYtVufkkeC0Hbne+P5VN/YMLnN9PNOf9t8fkI=lKqoO0F8xKDfxG34c1eTwnqsF/pkO1YhtubeMYEsff4=pHUGvpzStRg1fT7e8s5BLDNGHR1Ocg9DXBiI39456qs=SJbvfAy39uCzwrtnQdXj6k/UdR+NaaSpMoeIgxsMqQc=qDXI+5PqIeD7mkJ4x3NO4h2QDweM9aYz85WlcBjtxx0=jioi2Dz26VVxWIWbPfp79KjZhxihARMec1A7Yq1qFz8=/9LEVuOualV+wrw3YZIG96cpA+nalYCTdnj9KdnP+FI=6ajFDZI759Ker4IKnBpX0Cw3ULGz1u1Ntq0Qdedr4+Y=U+oNeS+KfA9zoTGeIPcWBPEi9V9j6VrRnyysa05dDlk=XkXiI5Q5yp/xqaGZV4cnP90jn/69dyaNn6k5kVxgjKk=7npUTyrFy5yp6Z6ipdnsMaZWdRtX5cdTxSgMo+c5B7k=4qfdGS7UHUe9L5hRhk+4OODQg0JTIpGD9z6VUl1e2s0=v3sq7ux6n8amMOZ2QXsiI6jc3nFlZu6n+KT5Voi03UI=64vbzyh12QLj9TVSlTp+bQvel5FqHQ7OBs+X5kgOd0g=d5/wq9HOdpWNQuOG54H0xWDnz35maJJLQVyGwN43Dpg=4p0UQfJ2kY4PbFRcPU07TQtR1Ap/ZdlLPJ0+VTjHuek=Xs/wx0HU/D+lXNvqYKI85kt4iwPlqwyV4PAzn86xqyQ=4NdTCs1sd1u5GDk4wQOaq2aNZTTWwH+jj95Cc42g9V8=wPT2Ncq1Oc0BKOuTmmmTFQAAAAAAAAAAAAAAAAAAAAA=9+tRFwAAAAAAAAAAAAAAAAAAAAAAAAAAAAAAAAAAAAA=rcR//9PABwM5xTw+fevBd9hkgcjGTkfWnh8fjT6WGPU=fBAGKkz71PSwdR4OevFOB54OfSlfuA8HkZ9akV/lMbo=ho26qRkGhaAcN4n+HyT+Ze6B8r53Pb/3j/smvM7hDHI=GGeMq68FSMGumlUurXOmnK6IvJlHzI+ATyh54+tPjkg=87WBV+nzYz+ddKd42RW247JU5Ugr3HT8qcZVPRvyqdU=7juilcarb2pClweei8mo/td7eEfZLXapH35W2itOVRU=eTsTzNu0SRNLuLgKL++kx3WP5VP496uwabaW7DyocMs=/GfmJP41jKq3pHRFKFt9y+s5AAAAAAAAAAAAAAAAAAA=pWNralMs20E1yUiiQtN/zzVdx/ACuk0/4da7flXNuLY=UfxTtsB+q8n9KiU1HcU5pLU6vTPhbbxzump3TMFVSPI=ExnPUZIrsdO8IaLprBrbT42k/vz/AAAAAAAAAAAAAAA=ctjokG0Y3AAAAAAAAAAAAAAAAAAAAAAAAAAAAAAAAAA=J55FIAEtAlz1PNLQBPPx/Wk+0Z74/GhrqBGZiSOmaY0=McAg5p2FciM2O9QtN6saaWoMieQDkjiqct3Gg+eRVx4=4FWk+gWP/9Tmww+lOB9K8LR2SGmPDc9aeG+bnH59aTs=W3AerAnOeP5VIHHGM5otcCRW/Wnhqm3cdx6tnrUgPTA=adrCHI5zkHHasnxF4ZsvEcW51WK9UHZMP5H1FCdmVGU=Z3PINZ0m80K58nUoyhx8rr91x7GsO51C1hyJXBI4AAA=13QXNqjpc1a5UjvLy5IFpCyo38cnAAAAAAAAAAAAAAA=2O6RnANauUYebJSlIuW9nbW5BhhUk9P4iPxNXhKQeSM=GT82OfzNYT1erNFsS5EgHXn6k5rS0vQtR1WRRaWc0q8=Z1TC/ix4H51k7JWbHJ21Z11h8LLubDalcw26n+Ff3jA=/XH612OmfDvRrNd08Ut3IOd0zYXPso/rmuedVydkYyo=r2R1dpZwWaBLSGGCMfwxIBVrCjAb5vqawe97mV2PEgA=MAAAAAAAAAAAAAAAAAAAAAAAAAAAAAAAAAAAAAAAAAA=pXATzvfr+dBm9T/WnZBca1wMiomugOpH50bICtLq9vE=kh50HturPl8TWifdYv8AAAAAAAAAAAAAAAAAAAAAAAA=SeI71z8m1fpVRiDKk+q3U/DTNg+hxVF3LHLMxP160+U=TY1c/9XlBJ09KkVx1rw7W0HclBHbIoyNw64peYx2/BE=mpVkHfNJgh4bjinrID+AoaBMkDDIwalBDAZP0FLW4Ng=8P3/AAAAAAAAAAAAAAAAAAAAAAAAAAAAAAAAAAAAAAA=/wAAAAAAAAAAAAAAAAAAAAAAAAAAAAAAAAAAAAAAAAA=a02uonLEMo2/SnKCXwFyx4+v4mtWdFzZsvDGqX4MttY=UvlBd29l2gj2zjP4Cuw0v4aCRVfUr0MGHKQLu/8AAAA=4VjKrbQiVVJ6HZaX4S0jTMGCyjLj+Ob94368CuhVVwM=J4HYcAVzSldts53JyJkZUwFwPoKeJRx1zips7CuP8zA=OtKJe2akBPN/yaPOx/Wn5Aw88Y5pDNz1pWAaZwvJPao=tNq9rCT5lwi+2eaLMCjN4otUGI98h9hjP51ny+KZnz4=TCBjoWOapR7jaKsmv3r9JAo7hQAAAAAAAAAAAAAAAAA=EJszznn3prLg/MKbvYYEL6Ug4BwMH6UN2EI3ufzo2jE=35oT1C5//9bjA2PcU9XI+91rxPUfkSxSjJBqTf2FKww=cGz3/Cn7sY28exNJpgP3DjpxUgbnk0IRKHPAGaer9Oo=Pap6jJA3bPNODkdPSm1rZAOD9Of1qrqWmWmr2/k38Kw=ic7SeCvuD2pLQFo7nL2/w2so3Z572aSPPyxooQ49258=6V02m6FpumAG0tIkcfx43MPxPSnKo5Kxo5tmupUdefo=1IstS0Zj1lHr/WniUgnNQ1YBwnwO30p4k9xSt1DyHec=880GbB5OOadkBG12iZ3uAAAAAAAAAAAAAAAAAAAAAAA=OXUdmU28VR8mGJiP9riqU3iO6lyI9qDPXGTVKHcDPls=2ef/AAAAAAAAAAAAAAAAAAAAAAAAAAAAAAAAAAAAAAA=up4OKVtAJ1x9PrSSKBjrmi3cBg9zSDqcntQ0IaRgY7U=I2B170bbh1P/1+F8wmpN/TNeL5jFDjP+NSLLtHBP50Y=2oEolzgnqealVgwOKWwChgG9vrTxJkjBP1NSrjJVkHE=ipA+BS1GKHweM+9PEnp+HNLV3EO8znP9acHA49KGMeI=X0p4kA4Pb9aFogsOEvP6Uvm5/D3od3qId5vrS+d74pU=2GwyS/hiz5rqo9WNU5dftoj8shfHZaQ7FOTxK/Cwxk8=uxqnLrd5NnMuzPXbxTUe4FV5ZJCDJIzH1JzSYwcDrTs=dBslGNpxmgAAAAAAAAAAAAAAAAAAAAAAAAAAAAAAAAA=OfpUtOwx3Q8Z+hp2cf4UxvUmRug7etOfBXPbGaRNiI8=H096AAAAAAAAAAAAAAAAAAAAAAAAAAAAAAAAAAAAAAA=FeK7jFD5PfNP3eh6UavQY9G5xTvNK/WlqBIso74+lSI=sMZB/ClZhoSLJg8VIJOx6UvesDF8wZBz2zTvN565osw=Og4SjjJ/SlExz1NJp21Ad5wzx60vmk4AAAAAAAAAAAA=LmRgB7nFV5Natk4Dljg/dFO0rhYpy6+7AiGEZHQsc1U=JdTu5gAAAAAAAAAAAAAAAAAAAAAAAAAAAAAAAAAAAAA=uO1J3GB1/Gk1qA4NgdKcCeppah1JQw5A7UKenrSd+gw=UdKkHIGaLO2oMUNz/iKfu/zilZgPz70uSSuP/wAAAAA=6kisVbjr3oLFj6UJO9gVgwSQc0cnp2FGrC40+hpD/sg=60031QH/0fPDwaaT1968awxVbHXgUu7vmkGo8ydeaUQ=mDgUWuBIHxjn604S9OehxzSa7ASJLkgH8al8w8etJDA=80jg0LMcdetAAZ8ctgAAAAAAAAAAAAAAAAAAAAAAAAA=Mc+VFgdmY4qB9SuXBBlC57LxVKNmNMgYszbmJZvVjUg=FPGTj196Wj0HcC2OBn6UKpPf3pNJiHrjPqaUc4zStYI=48nOOuPpSjpRa7C4oPPH5UufSiyTuCJU5x2pAcYJpOI=+gyQE/j/AAAAAAAAAAAAAAAAAAAAAAAAAAAAAAAAAAA=PAx165p/saaXmSLjt7UmOp6VKjpuO4c8dPSmt1POfwo=a2Ez/9LzsjP3R71GzY614sW2ykNMncnj2pnmbTx+dO4=30CwefjOT+nSlE/P07+lGr2FoP8AAAAAAAAAAAAAAAA=O+gxRMccmnfb4k4aUZ9Ac1PvPRARSaxGo+RGJ9+KrNo=lO/3SqAelWosCEu0zAyyEn3NSgAAAAAAAAAAAAAAAAA=6DtT8c8jOKl82waDucgg8Z9KkBwvSk7rUA3dMUbxgY8=TmldoAAAAAAAAAAAAAAAAAAAAAAAAAAAAAAAAAAAAAA=FODAcnn2xUu+4EgcjpSg889KbvsAAAAAAAAAAAAAAAA=1JARxgAAAAAAAAAAAAAAAAAAAAAAAAAAAAAAAAAAAAA=bjtUu+4gBwc9qUk9uppagJuz+VICOw/DFJRa1Fc//9M=4WSNT2qtLFg5GM14t0MqupH9ars2CScHFNNXuBC0hPU=phnVcb2AxxzV6PQZCdSCkYBbHccCmNfSsMrhVPTiqVk=PUNRjTyOQGckdvm4p8WC3OMUSaWwJE2cseB9KdjOPXo=Gs72GTx43KcDjrin8kgHk+pNLmBXH9skflT88H17ZqY=6swsOjyxCjAOO5pxbGRQmh2GKeRgYJp3fJpc2g7ajsA=BOOwp+cdPTj2ockSLnHPcUnc55J6VPNoOw5Tkdvr0qQ=GOM9SaHK41oS8dRj8aRT6gZob0EP6+tOzgjHX6UroGM=wcY4p457ZNJtJWC3UfgjjAp27kUrpoY9TwPr0FBPTB4=aTZOrFwDjPNLuHf6UcyCzEyCQKGxyAPrxRddgZ//1OE=mySOaY3XmvE3GRS7WB3A4x+Nc7NduGJAA96uMRlJ5JQ=jmQ+/pUWM43E9fStF6AO256Hj8qmwRtGe3ai19Q6CgY=CD2+lWYgQQTnGOc0nsA4Z/iP6U9QflIPJ4qXrsOxMpM=jPQ4x0p2OOCOeeO9SnoFhwJ5p5Jxz69+KVlsMd+P404=4zz9DkVIAeSP14pxyAMNgigNgTPBGKeMn7xxRZAOAwc=j+VHOfrStoA7HPU47U8YOPX6UB5jx169KUZzx+lS79A=CRacBz1peoEigfxHn3qeMZTgjg9qfQaFYlj83BpCMjo=0rgLz0BIx70vYHPOaGkJihcAAAAAAAAAAAAAAAAAAAA=8sep4otrcD//1eHbPfp9KiJ55rxdSipeMUtpSAeFx18=WuZPOMHPtWkFuAzPcZBHQ0mMnOfartZCHorcfrxT9uA=0apaD0HIG6VOM/wnjvUtXGP6DGKft6gD654qWuwrakw=mOMrkZ/PFK7ZJLHPek1pcewq5PY04fKBiktRjxxgCjk=GOMe9FtRDgoXHPJ4o53ZPTtx0pWV7D3HDjtj2zTlJ5Y=9s0codBzLgAAAAAAAAAAAAAAAAAAAAAAAAAAAAAAAAA=c9KUYHU0lceg5cZBJNPBDHii3UB4ODUsX3iMnJ9qnUI=w9sjBGTSKSzAgcZp2uA/J/u0mc4NTYQ4EDBOefSjPzE=yKTXUYZyeT36U0v39PSiwj//1vl/RfixqFmVj1aNbuI=xjeMI/8AAAAAAAAAAAAAAAAAAAAAAAAAAAAAAAAAAAA=HcfejsO6Zb1iXbapjku2ODWAJOc9sVhFOwxBnj604Ek=Pb6Vd7A7D8kDGMnHFPwDj2ov0uA9eeMD61KCFGMewwI=ofZMB+TjOMf4U4ZTkDj1pXvoBLuzwOvsaVmyeeSevtU=N2MeD7dPUU9TxjgnNTfUaF3YxuGKVW+YAAAAAAAAAAA=PBIzntSnI6AZ747UluG4bc8D61Ku7jHP8qL6BceF65w=cUdScikn0bC5Iq8cnAFPyX+6p/Kk20C1FBJOMD86cBg=6AY/WlbsA/BAAAAAAAAAAAAAAAAAAAAAAAAAAAAAAAA=+MYppBzlc1N9dwQoyeTmlK9DjHtmi7YDuOB7Up4OAec=2obvqJApz/EB9RmkYDPf2HalfUD/1/ho5656UbsMuDg=PrWt09CT1XRmubPw3pK3UrtJco1yAzZ2qxwo9uFz/wA=Aq0knLDjHT6V5lRJybRaJlcnH0qVG9T2rNhuSrgHkdc=gd6UcH/CjRj2JUzz0x2NSKffg9qz3uMkbPy46/SlByc=jtRpcCVecfSlyMjmkA/IIGD7GpFON2O3rUDvcVcAAAA=kfrTgPmGeg696JabAn3HbeBgfrQFGfQ4pXsw6C/XipE=cHPSjcOlx+e1OHUUOzEPGW4AAAAAAAAAAAAAAAAAAAA=RxmnqM9Op7UtwJRHkZPAoJBwFH40rBcUKM4zzThkelI=0QEgO7huKNpGD15I5OPcj9KTd3oDF2AcgnnpQuVA4Bw=9/SjoIkC5HKgkUZXH/16TXVBcaRyBkH2ppAJzQrdx34=5//Q+Gj15HFOSJ7iRIY/vyMEXHOSTgfqa2aVtCT2jxE=KkGoi1j+5axpboPZFxVKE/dz6+teXy3Rdy0jkkc8H1o=so2D04NS49g6kox97r+HNSA88cVDQ7jgTjHt2qVDyBg=6UNLoBI/LYH3scU4N8wAAAAAAAAAAAAAAAAAAAAAAAA=qQabSeg7skB5wR7ZzT9wwOmTkdamUV1BXuOXOMinqeQ=59OKVhscQeeg4oIOe/4UaaIQAYHPWpVyDgdcdaTimDY=Oxg+1SKnykk4+tLlFceB1zn2Ap4UlcnGPWhq2w0ORT0=zipY4+7c+pIpJKwNisc4G0cdvWm8dVFEUJigc81KpOA=A4+tTy6DHDCnr+VOHl5+dsE+2aWiB3HKhJ3E7/8AAAA=9cYwMHjcTzRYQwkk5Jzj07U4HOOKTsApKkDbnp3FIc4=MGnyq4XP/9H4c5HAxnp0rofAll/aHjDRoWTKrceawxk=4jBf/wAAAAAAAAAAAAAAAAAAAAAAAAAAAAAAAAAAAAA=gUdCrlpGO4benYVOrHcN2ahp7BoiRXJP9MVNk457DpU=Luh3H4zjqfrU0XOCRwWAJ/WoabGPLZc5HfPSnIctyes=SabBExHyfKR+VCnnjGfepSbKdh4PGDnpxUmOAAAAAAA=O4kPJOOcdqfj1z6U7PoK/Yceox/KndMYB5qLMd9BcHk=x/KlGTz+lDXcNCdDz8x7dcVIQuMZpX7AKMAEg+2KXcQ=kdsUvMRJuIA29Ce4p43EY/lQ+49EIIgDz/PJp6o2en4=FN3auGguNv4+1SLnjdmps7ahckVRjDfWm4OeOefWiwA=o25BdQAAAAAAAAAAAAAAAAAAAAAAAAAAAAAAAAAAAAA=triEC5YdM+gFLjaaLX6gf//S+G+RjpXf/CmAjVNUv8E=/wAAAAAAAAAAAAAAAAAAAAAAAAAAAAAAAAAAAAAAAAA=rOw0WVXv2qYAAAAAAAAAAAAAAAAAAAAAAAAAAAAAAAA=CJgDlcc4Gc1NGSNobOByOfWo9AFVsn2xxU0ZxxjJNEo=/cqOjJlwckgbeTijkkkcDPBrPoU9tCQZyMc5p6g56ig=toS9CXHHApx4weCB+tS7sBxB6MvSlCsccYp9AAAAAAA=P608AnBBpPayEPx9DT13D7uCDU28wJF45C9DTiD3+uM=0p20sCJAuB06VIE4BxxmhhYeE496kSBvlOOPfipWwxc=yjxjH+FOWHAw2c9+KLt7CHhAPWo2Qk8nBpNALtGOgK4=KkRFPAyARz6j/GkgGkEDlgQB2owuSBn169aNbCEUEn4=UEgds0u0buE59N1CukM//9P4dLDdn2r0/wAAAAAAAAA=ILk8NPPFbg+wG4j/AAAAAAAAAAAAAAAAAAAAAAAAAAA=a5Lu12MlTPGf51ZXgZ7VnK9xiow65G4jpUvPXNS27jE=4OCBx6dakUjaP15pXewIkQAAAAAAAAAAAAAAAAAAAAA=0hxnA+UL0pQR1Hp1xxWTvuaXHfe5Xk9eDwKeo+UsCAM=GTindq7IJVHIPr1zUiqd2Ap4GaVxbi88EhV54xzS+mQ=0uoD8ZwQOhp6D05+lK7vqA/bnpnj9KeF9KNtg1HgYPI=KlCBsDvT16gPUc496lCcBsD8KV31BE8YwMnJGcGlZck=yDk+56CoWjBgM8jHPQheBTuGz83IOCBz/wAAAAAAAAA=wppjZf7oxii4hRvXODinMxbqFB9cYpMQFd+S45/nSGI=IzsP4Z70m2txjmLL8xQNj0pjCJ0LIHUbujYNNXsI/9Q=+JLy2ayvrq2YfNDM8Tf8BJH9K9X8NQi1+HlmSMNd3ks=Oc8ZAAAAAAAAAAAAAAAAAAAAAAAAAAAAAAAAAAAAAAA=wQAAAAAAAAAAAAAAAAAAAAAAAAAAAAAAAAAAAAAAAAA=jr24qUfc4xjvStrYCROPm647VNGCcn5iAAAAAAAAAAA=7CpVHUHpmosVd7jhjcBxk1YAAAAAAAAAAAAAAAAAAAA=kc81KAhOOoHvUtgOAz6Y756UKhY84p+gKw4Y2jinrz0=BgUmgJVBBAx79amjKAHgZHb1pAPHPYD6VLtC4VSMnO4=J4ofmHUkRF6kZbnCnpUijaC2eMcZHGal7hcafmA6j18=8/lSqjLznj+VU7LQGTCMN94Z/lUqQjAyvA6NnJH/AAA=qb2AbJAoIIO4Y64xQseAOePQVNhXFMWR04HtR5QUHOA=frTAYQAAAAAAAAAAAAAAAAAAAAAAAAAAAAAAAAAAAAA=CuFyGJye9GzA/9X5A8bLGPGGolGUqWjZ8dA/lpv/AAA=7dXpksP2Pwv4atWUBk09ZGHoWAJ/UmsKzXJBCVzKVTw=Hrwe1WlAwBkE4yBjmsW0MkHBHAzj1p3G4cjGKjQZIg4=QR39akXOP6VLtugJFPOCT+NS9lBGBjp6VN7D1JEXd8o=PxqViVXagyvvSurgkSdDgEZ7U8DJGSMZ5OOgpNoepKU=ugHXsPxqdFLliCOB3GBk1LsMnKpE4AfcR3HAPrQi4zg=5Oc89qVo2ELkM4QZ34z+HWpiM5A2hP50aAPVFPAwFX0=M/1pyR7SAQAAAAAAAAAAAAAAAAAAAAAAAAAAAAAAAAA=TKgDH7uRxjuKNLBuPzuJ3DAGBgAAAAAAAAAAAAAAAAA=P8r5s7jjqRtzUoRWOY2wcfdK9ab5XuLUFXOeMZGKlZA=4+ZR7CpfKMBjjoeO1IUxg8e1PSwho78fnzSMQf4Cvpw=80g6EZ+8cAEdyDn/AAAAAAAAAAAAAAAAAAAAAAAAAAA=QRTdgjPyhefwqtGI/9b4n2S390+4l57l8Z6lmY4/ma8=c/FyiK/WCP8AAAAAAAAAAAAAAAAAAAAAAAAAAAAAAAA=hyRu7da57jJowW7cfzqTO4Zxk0g6jxngGpMcnjnFQ2M=sSLkYIxn61JjB7c0m30BE0WSMHjB61IAAAAAAAAAAAA=FQ8AAAAAAAAAAAAAAAAAAAAAAAAAAAAAAAAAAAAAAAA=x/kUJA2OjBYseMH1NPHGcj6VLsBNCHVJCGVVbC9Pmb0=fwpqAsV/dsEz94A/1o5na4WJwBxgYHuc04KMnb1pO7E=IlWPaFzyDzirsdvtyQR0ySeKVr6DJvLC89h90HqT2pU=INy/MoP0NK99xdCYKOuACOMelO2DqnII5ppjHo7jiOI=3KPQ81NsLksc5Y557UugtwEYyMgD6U8RbSQ2Pw7expY=iBDTCdwOBTnhKgbh0ou+wXI/IOBgDJppi2YJ9ORSC5E=umQpUcHvnP6dqaYpG6qQPTHPrmlEbIjGCMKc8ZHy81E=SKGwe4HQ1X5CP//X+QPBdr9s8U6NARw14jH3CfOf0Ws=1DxFJ5uq3RLfLv2j8AAAAAAAAAAAAAAAAAAAAAAAAAA=cH2rFrqxvUlXJAOMZ9qkAAAAAAAAAAAAAAAAAAAAAAA=Sj6ZOMVNmG5MvHftT1Xf9T0pNDuWokJjyMcGnog+91Y=96i3YLki4GOTnHOakVSfm5A9PWlbce5KBhvXPU4qdQQ=+g65pJaiewFM/Lk4zyOlSBQD1xj3pegyThhxuORnp/U=NPAYNjBHtnpQ49EBMO2BUqJvcBRknjA5qWu4iVgMgdw=Yzj6VbhJcgE8c4A6Yod9Q0LSxsfvc7uAN2f1FSpFk4I=T7YOMVNmAqJlfvA+4HSphETxznHFO2giZIiOAAAAAAA=laEnHUe1R13GCxZOO3XmpWiBQEZxjHPWmxEYiYkDqPc=odDhR3xxmkMjVSq8SYOeoqBlIOC2TRsIikLj5WJ9xjk=qMFkY7SfqO1JjGNvcHeeQQRgdD61HIhG4YwQegGM+9M=6gf/0Plr4UWv2nxlaHg+RBNKeOny7R/6GK63VX8y+nc=ByGlc5/Guav/AAAAAAAAAAAAAAAAAAAAAAAAAAAAAAA=cZKOSOc49qkX5uemPalZgth4Pc/SpFyARUtDJB0JJxw=dqkQdD/SpAvIubf5eM/49aUAAAAAAAAAAAAAAAAAAAA=tUyZBPv0OOabWlgJlG0HA+lWFX5PmyefzqGn0C4qqgM=hUVTj3P86kVRnkDmk0HUm2ggkknPHAJpxXBx6+1F29A=ESovA+UkDvUygj5ScAnnjmm+zBE0aBSeBz+VWYkbJ6g=4qXfcLlyKInIcLk8H/A1ajiyoyMDGQo+mfTn8BSctAI=byckAAAAAAAAAAAAAAAAAAAAAAAAAAAAAAAAAAAAAAA=Uqxk9e/60gHGAY+bAAAAAAAAAAAAAAAAAAAAAAAAAAA=Iziq7x7jjb156UkMb5CqORnBx0qB1GTwcVSTBlQp2HQ=FRN0wKBEJ4ww649KQMChA6DpTSaVwZ//0fm/4Mxf8Tw=1O5YHEGnkbvQs6//AAAAAAAAAAAAAAAAAAAAAAAAAAA=0qRQox271lqUTqMjBp6ntnt3qb21JQoHA61KoOehpNg=72JkHP16VKuOB3JHGelJsC+oAX5+gA49KToc+p5zUXQ=rFWHgAjg4/nTzyxH0xSTDQnjGAM856/0qfaZM9AvT3Y=/wAAAAAAAAAAAAAAAAAAAAAAAAAAAAAAAAAAAAAAAAA=qYL8xLDHHapv2GSqoxhQq89STn9KsCPB6O23gk/1pyY=JFlYwWXJbcexXGP8/wAAAAAAAAAAAAAAAAAAAAAAAAA=tLbZflT65I7+3rUtjLC24IOeR6VOlvjheo647VLEi3E=WbhJXRdyDBkGPXgfTv8AAAAAAAAAAAAAAAAAAAAAAAA=G33/AAAAAAAAAAAAAAAAAAAAAAAAAAAAAAAAAAAAAAA=kEAe1VprcYbrkD0pXVxlCUbTw7EEcrng1WcHkZqtloA=2Q5IUjI2nrTWi2tkYIb+Y/8AAAAAAAAAAAAAAAAAAAA=P8T3GDlYoo/rxIf6ip58l+a5Kl/asENRcg9TxjjipFQ=y3ynPPSo12YEvIxjPI5qbGB/PipbH0FVSDyO1OA5AAA=FSCJk4I+8fxqyECOq+gzg1F33C5ZQZO3+napAueDk58=T0qRk4QIApIJPXvg+lKFy2AevP0qdmCJlyc4znsT9Ks=IiHAXH938BwP5UtEmg6kiJhup4PJzmp4IvlVSCQB39Q=5z+vNNruIkCnBZlOD0J4p6oNwVT0zxUu8dRk6whcKPo=nj9KmijZ+64z36nPp/nFF76piNC1tjuyq/5/z/StGIA=IAVRuY4XjoB1P8qn1AvQ24dsMgPocYJ/L+mK0obTeBg=VsDn5jn6fh1rNsCwtnwOMj1qZbXgYT8RUMZdAREEak4=1eGcqVyxHvjPpx71G1mSx2ilcQ02PUsPyFQmwbcdrIg=hGG3D69+1GoXIptOkDkK4yOxGP1qpLZPHguBjsM5NVc=sBUljYAj5evTrVKWMgE849qtaDKTpj3FQuoBGB9admI=K88JXcCMGmAE4V1A/Hr/AAAAAAAAAAAAAAAAAAAAAAA=YDSXipnHYIn/AAAAAAAAAAAAAAAAAAAAAAAAAAAAAAA=9euMfjUPa1xkqcD6DOTTmHz89MdKl6O1wQq8EH/69PU=HzDH4UlFrqBbQFTkDHWpcZZmI/OpalsPqSop3Due1Xk=UMJ3NgyDp6L/AAAAAAAAAAAAAAAAAAAAAAAAAAAAAAA=Llh61ajUAZI6DNTZ31BEygsBj68mpkIcHcMgnaOfahI=YmWUgDcoF2AbVXP3mJ6n2xnirAtzGTjOAoBOO5FKwD0=YiT06VbtopOBFGjSFvlLJkjPHHvUyTY9jUNq0OIy6yM=AYdkUhd3cD2AOKvWVoSw4Abj6VDbsI14LUjBXluxHAo=1rOwkEZ2c5689PpxWbf3AaQsQcDYV4x65qdNJdmAEbY=ScDA61lza6iLUliBEsAUZTlz97LUiadzjGc9qVx3JR4=H7lkZ/IKRj+KT5R+Gev4VmywRwvhQWOc/dIz+GKLu4Y=j1Ks0S9k2qOAfSsq7TaWBbPt2NXG9rBojKm4G0DDE54=vFZ8gODk8mtYpgUZgR1x+NVpFJUgHa2RtP0IyP1q0rI=Blefc4y5y2MZ/DApigsvB+ZeKdmkB//U8B8CXEUHw5s=3dKivLqTHaZADt2xjOPqtVZLiEsf3sfTP3xXNOM1Ulc=Q4xb2RNHcRttHnR5bGPnFTCeHdu86L04dajll2Hyyvs=EwuYTz5seOf4x/n0pTcwFlBmiBPQBxUezl2Dkl2HC4g=cDE0XTPDr/j9alS4tyf9dD0/56L/AAAAAAAAAAAAAAA=WzNkTQg4/wAAAAAAAAAAAAAAAAAAAAAAAAAAAAAAAAA=Mt2l1bo6tNcW+ByQZF/xpWv7eUjM9v8AAAAAAAAAAAA=KE+xKt1b45ngAAAAAAAAAAAAAAAAAAAAAAAAAAAAAAA=nkltyj5JvZMlFzbFh/pFvj/rsv8AAAAAAAAAAAAAAAA=5f8AAAAAAAAAAAAAAAAAAAAAAAAAAAAAAAAAAAAAAAA=VuAOB++X/Ghxny7C9lP+Vly3vLRWC/arbr1Nwv8AAAA=+22cZA+0wE5OFSZccDnvjgck/T15nlm+g3TqLVxf3Fo=tri0kB33VqO/yzKQBke/+c1owXdiNhhu7YHAbcZ0z0w=+tTKErbDVGo38L+4vxT2bOM3tp6DFwn+NbFtLYqSGvY=04Pe4Qf1rNxlbRD9hW/lf3Gzay2O7Jv7Pdkf8vKc/rU=u2L6eOmo2KHI2k3ScfrXPO6eo/q9b+R/czXgGnAEtqM=YZxzi7j/AAAAAAAAAAAAAAAAAAAAAAAAAAAAAAAAAAA=H9zJFbTWI26lp4Xt/pkf/wAAAAAAAAAAAAAAAAAAAAA=pc6egewq/wAAAAAAAAAAAAAAAAAAAAAAAAAAAAAAAAA=1+orLuLqwJ51CwPpi4jz+OWq4TuHsKz+w/uZmTXViCw=xvrHav3v9KTp7AGsW8vbEnH22zyPl+W7Ug/ma2hFvZA=fV6/8j+4yri6ssFlvbPB4/4+Uz/Osya9tOR9ttMf9fA=n+NbqE+wvYVf5X9xSlu7M8i9ten/AAAAAAAAAAAAAAA=tCrH5h56HnI6c9eKtRl2D2NX+V/cVZry1Th7q3DZOQY=Zcgg/WokvLYOyi5tyW5UidTn8M+9VyTvsL2VR/Zf3H8=////2Q==

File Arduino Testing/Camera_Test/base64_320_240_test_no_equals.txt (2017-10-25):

/9j//gAAAAAAAAAAAAAAAAAAAAAAAAAAAAAAAAAAAAAEgtRBFEEAAAAAAAAAAAAAAAAAAAAAAAAAAAAAAAAAAABgYNCQoICw8OEBAPDg8PERMYFRESFxIPDxUdFhcZGhsHBsQFB4gHhsgGBsbGgEFBQUGBgYMBwcMGhIPEhoaGhoGhoaGhoaGhoaGhoaGhoaGhoaGhoaGhoaGhoaGhoaGhoGhoaGhoaGhoaGhoaGhr//gAAAAAAAAAAAAAAAAAAAAAIQAAAAAAAAAAAAAAAAAAAAAAAAAAAAAAAAAAAAAAAAAAwQFBgcICQoLAQAAAAAAAAAAAAAAAAAAAAAAAAAAAAABgcICQoLEAAAAAAAAAAAAAAAAAAAAAAAAAAAAAAAAAAMUEGE1FhByJxFDKBkaEII0KxwRVS0fAkM2JyggkKFhcGBkaJSYnKCkqNDU2Nzg5OkNERUZHSElKU1RVVldYWVoY2RlZmdoaWpzdHV2d3h5eoOEhYaHiImKkpOUlZaXmJkmqKjpKWmp6ipqrKztLW2t7i5usLDxMXGx8jJytLT1NU1tfY2drh4uPk5ebn6Onq8fLz9PX29/j5+hEAAAAAAAAAwQHBQQEAAAAAAAAAAAAAAAAAAAAAAAAAAAAAAAAAAAQpGhscEJIzNS8BVictEKFiQ04SXxFxgZGiYnKCkqNTYNzg5OkNERUZHSElKU1RVVldYWVpjZGVmZ2hpanN0dXYd3h5eoKDhIWGh4iJipKTlJWWl5iZmqKjpKWmp6ipqrIs7S1tre4ubrCw8TFxsfIycrS09TV1tfY2dri4+Tl5uc6Onq8vP09fb3+Pn6/90AAAAAAAAAAAAAAAAAAAAAAAAzwc45NKpOfvHGfWvCaQ7km4+pqG506G8A89SHHRkYqwv0IpK6YeZzHiHwhLfoXiInlXow4fHqezfoa84v8AAAA051EvzxkZDJk/nXRCSOinLTlIEIxjqD+OKmSR48spBUPvyK2hpobMtibzcgFVTuSf51C8RUloj8nXnj8verXmwlaDRKOBGN3qfQ0jeYGDI2SeozxU2ZdyxFO3HzkdvT9It7QrS01C5ZLvUBaMELK7DO89lGOK0pK8kpPQibtG6O8NPu4NLJtrO3jik43GRPNft82GwvJ6GTOM10V1YrfwtsnlivwnmKgEl3dJ1OXIAWMc/wIVx6c160FdW6HFK61ZgiaraaPPGjxJd3qO2+4nKyRBcYysakqW9ecj8OddILvUm0W8NnNLYuD5M13P5FvyeqZKiQj0UORipg21yw/r/gAPTWRQdrC21CSTxJqb6hcFMJJHM8oPbaWbB9B+mKvp4klFkY9J0rykIK+czpBEox0dzyTxkYkXP93tSUoQut33AalJeRxs/i+60SYxWOpu0TcN9lYhU56BzyR9OO3IrFHgrnt3L2SQRyAk+Y8YlYn1+YYz74zXn1MS72i7nTGimjELrUbieV5p5ZJndsuXYnn1qITSjgZI9e1ccm5O7Z0JJIsiT5o8OOn8Q9q9a+GHjEyBdIvZiWVc2756j+7+FctZMlFmVVXjdHqhbDBwcjv7ioLKY2FwLQkiCYlrZs9D1Kf0R+VcDjc57mluYHrz9aCzAnk5z60egCZb1IH1pwJ5+Y8rnNJdAHsfVjmo2Oc8n35otcVyJy2CM/rUOWB6mqtoF8Uad3QN+tRHPYmmlYNCGTJx8x4qs+c53H86pabiP/0MwVhUgIwT+teEmMkDelPBweev0pdNQHZ5yBz2qG7sLLVEPL1KBXGMbx94UXaeg07anAeI/hrd2iyXmhMbmAfMYyMEgH8iPyP1rg/M2uySZSRfvBhgj8K6qc+ZeZ1QnzEok0+Gi4JPJ9alWYOQuCWz0Pb6VupKw2raD3ty3zBgG9AAASAnldu3HUGkxoVivLKccdc9PrmlhuXzhMg+o4x7g9aUzWd0FrnX6B4pgs4HS9WSSYLm3khPllGPBywG4/TIHr4ldfFqN1eQC01SVbW3CCYWsUqxxSZH3tq8Z4GT94dyesXo0avPHlOWpDldyzBbQagzpY2kt2IWBYWy4jjHrJMwAARx8xUj3rPn8aQaVNJDrAAAAAAAAAAAAAAAAAAAAAAAZGOmO2k6sacb/wAAAAAAAAAAAAAAAAAAAAAAAAAAAAAA/Sse51W5upi11M8jkYDuxY/rXlVKsqj12OuNNRKxkYkcliSD/ezz+FKrBCN5LL2wOhrI0sWCy/3R+NRo3lH90qdp6EjpUc2mwWSDc2CJZBkdAOv5VLBctp8qTxSGModwj7sbGByDRJ6bEtJqzPoDwB4zg8V6YSCou7chJ1U55xwMPY11U0K3MLQOdoY5Rx1Rh0IrzakVBtHIlqT2Fy1zG0HcgJdQnZMo9fUex61dzyf7vesmtWAoTIBJA+ppDgH18pSvYQ4NxwMnmoGOPrVLYOozvg9OtMY5ySOvrR5CI278aomPPI/GmgIJCDnFVnrRO4H/0cdcdzxUyue3T6V4YyQVgc9KfnPXrUt6WAcDg8jrTw/fNS7jJorl4jmM/UetYs4j8G6d4ojaSJVt9QAyHUcH6inFuLuOMrM8c1jSL/AAA101tqCHIPBPceoNVlugy7fu46E9RXdCXNZo6r3RZiuMacSAHgkN2pZWLk5wqjoM/MPw7VpezuCvYjyEbOBv7MQ5FK5MgGevqalp7lLUdG5LEEkk5xzwa1I9VmS3eFjGWYPDtlnQe2eB9cZoVRrYTimiK81+8uo4oL65mljh/1UTMEon+6vRfwFUzJJcAAAAAAAAAAAAAAAAAAAAAAAAAAAAO9SELkfKp49KylKxSV9w8yRTsOFyOGocDBR2znrSb7A+hC97DacXUsaL/eY8kf41WbW0uTss7ea6J4G1cCqUG8V7Et9BIYtVufkkeC0Hbne+P5VN/YMLnN9PNOf9t8fkIlKqoO0F8xKDfxG34c1eTwnqsF/pkO1YhtubeMYEsff4pHUGvpzStRg1fT7e8s5BLDNGHR1Ocg9DXBiI39456qsSJbvfAy39uCzwrtnQdXj6k/UdR+NaaSpMoeIgxsMqQcqDXI+5PqIeD7mkJ4x3NO4h2QDweM9aYz85WlcBjtxx0jioi2Dz26VVxWIWbPfp79KjZhxihARMec1A7Yq1qFz8/9LEVuOualV+wrw3YZIG96cpA+nalYCTdnj9KdnP+FI6ajFDZI759Ker4IKnBpX0Cw3ULGz1u1Ntq0Qdedr4+YU+oNeS+KfA9zoTGeIPcWBPEi9V9j6VrRnyysa05dDlkXkXiI5Q5yp/xqaGZV4cnP90jn/69dyaNn6k5kVxgjKk7npUTyrFy5yp6Z6ipdnsMaZWdRtX5cdTxSgMo+c5B7k4qfdGS7UHUe9L5hRhk+4OODQg0JTIpGD9z6VUl1e2s0v3sq7ux6n8amMOZ2QXsiI6jc3nFlZu6n+KT5Voi03UI64vbzyh12QLj9TVSlTp+bQvel5FqHQ7OBs+X5kgOd0gd5/wq9HOdpWNQuOG54H0xWDnz35maJJLQVyGwN43Dpg4p0UQfJ2kY4PbFRcPU07TQtR1Ap/ZdlLPJ0+VTjHuekXs/wx0HU/D+lXNvqYKI85kt4iwPlqwyV4PAzn86xqyQ4NdTCs1sd1u5GDk4wQOaq2aNZTTWwH+jj95Cc42g9V8wPT2Ncq1Oc0BKOuTmmmTFQAAAAAAAAAAAAAAAAAAAAA9+tRFwAAAAAAAAAAAAAAAAAAAAAAAAAAAAAAAAAAAAArcR//9PABwM5xTw+fevBd9hkgcjGTkfWnh8fjT6WGPUfBAGKkz71PSwdR4OevFOB54OfSlfuA8HkZ9akV/lMboho26qRkGhaAcN4n+HyT+Ze6B8r53Pb/3j/smvM7hDHIGGeMq68FSMGumlUurXOmnK6IvJlHzI+ATyh54+tPjkg87WBV+nzYz+ddKd42RW247JU5Ugr3HT8qcZVPRvyqdU7juilcarb2pClweei8mo/td7eEfZLXapH35W2itOVRUeTsTzNu0SRNLuLgKL++kx3WP5VP496uwabaW7DyocMs/GfmJP41jKq3pHRFKFt9y+s5AAAAAAAAAAAAAAAAAAApWNralMs20E1yUiiQtN/zzVdx/ACuk0/4da7flXNuLYUfxTtsB+q8n9KiU1HcU5pLU6vTPhbbxzump3TMFVSPIExnPUZIrsdO8IaLprBrbT42k/vz/AAAAAAAAAAAAAAActjokG0Y3AAAAAAAAAAAAAAAAAAAAAAAAAAAAAAAAAAJ55FIAEtAlz1PNLQBPPx/Wk+0Z74/GhrqBGZiSOmaY0McAg5p2FciM2O9QtN6saaWoMieQDkjiqct3Gg+eRVx44FWk+gWP/9Tmww+lOB9K8LR2SGmPDc9aeG+bnH59aTsW3AerAnOeP5VIHHGM5otcCRW/Wnhqm3cdx6tnrUgPTAadrCHI5zkHHasnxF4ZsvEcW51WK9UHZMP5H1FCdmVGUZ3PINZ0m80K58nUoyhx8rr91x7GsO51C1hyJXBI4AAA13QXNqjpc1a5UjvLy5IFpCyo38cnAAAAAAAAAAAAAAA2O6RnANauUYebJSlIuW9nbW5BhhUk9P4iPxNXhKQeSMGT82OfzNYT1erNFsS5EgHXn6k5rS0vQtR1WRRaWc0q8Z1TC/ix4H51k7JWbHJ21Z11h8LLubDalcw26n+Ff3jA/XH612OmfDvRrNd08Ut3IOd0zYXPso/rmuedVydkYyor2R1dpZwWaBLSGGCMfwxIBVrCjAb5vqawe97mV2PEgAMAAAAAAAAAAAAAAAAAAAAAAAAAAAAAAAAAAAAAAAAAApXATzvfr+dBm9T/WnZBca1wMiomugOpH50bICtLq9vEkh50HturPl8TWifdYv8AAAAAAAAAAAAAAAAAAAAAAAASeI71z8m1fpVRiDKk+q3U/DTNg+hxVF3LHLMxP160+UTY1c/9XlBJ09KkVx1rw7W0HclBHbIoyNw64peYx2/BEmpVkHfNJgh4bjinrID+AoaBMkDDIwalBDAZP0FLW4Ng8P3/AAAAAAAAAAAAAAAAAAAAAAAAAAAAAAAAAAAAAAA/wAAAAAAAAAAAAAAAAAAAAAAAAAAAAAAAAAAAAAAAAAa02uonLEMo2/SnKCXwFyx4+v4mtWdFzZsvDGqX4MttYUvlBd29l2gj2zjP4Cuw0v4aCRVfUr0MGHKQLu/8AAAA4VjKrbQiVVJ6HZaX4S0jTMGCyjLj+Ob94368CuhVVwMJ4HYcAVzSldts53JyJkZUwFwPoKeJRx1zips7CuP8zAOtKJe2akBPN/yaPOx/Wn5Aw88Y5pDNz1pWAaZwvJPaotNq9rCT5lwi+2eaLMCjN4otUGI98h9hjP51ny+KZnz4TCBjoWOapR7jaKsmv3r9JAo7hQAAAAAAAAAAAAAAAAAEJszznn3prLg/MKbvYYEL6Ug4BwMH6UN2EI3ufzo2jE35oT1C5//9bjA2PcU9XI+91rxPUfkSxSjJBqTf2FKwwcGz3/Cn7sY28exNJpgP3DjpxUgbnk0IRKHPAGaer9OoPap6jJA3bPNODkdPSm1rZAOD9Of1qrqWmWmr2/k38Kwic7SeCvuD2pLQFo7nL2/w2so3Z572aSPPyxooQ492586V02m6FpumAG0tIkcfx43MPxPSnKo5Kxo5tmupUdefo1IstS0Zj1lHr/WniUgnNQ1YBwnwO30p4k9xSt1DyHec880GbB5OOadkBG12iZ3uAAAAAAAAAAAAAAAAAAAAAAAOXUdmU28VR8mGJiP9riqU3iO6lyI9qDPXGTVKHcDPls2ef/AAAAAAAAAAAAAAAAAAAAAAAAAAAAAAAAAAAAAAAup4OKVtAJ1x9PrSSKBjrmi3cBg9zSDqcntQ0IaRgY7UI2B170bbh1P/1+F8wmpN/TNeL5jFDjP+NSLLtHBP50Y2oEolzgnqealVgwOKWwChgG9vrTxJkjBP1NSrjJVkHEipA+BS1GKHweM+9PEnp+HNLV3EO8znP9acHA49KGMeIX0p4kA4Pb9aFogsOEvP6Uvm5/D3od3qId5vrS+d74pU2GwyS/hiz5rqo9WNU5dftoj8shfHZaQ7FOTxK/Cwxk8uxqnLrd5NnMuzPXbxTUe4FV5ZJCDJIzH1JzSYwcDrTsdBslGNpxmgAAAAAAAAAAAAAAAAAAAAAAAAAAAAAAAAAOfpUtOwx3Q8Z+hp2cf4UxvUmRug7etOfBXPbGaRNiI
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

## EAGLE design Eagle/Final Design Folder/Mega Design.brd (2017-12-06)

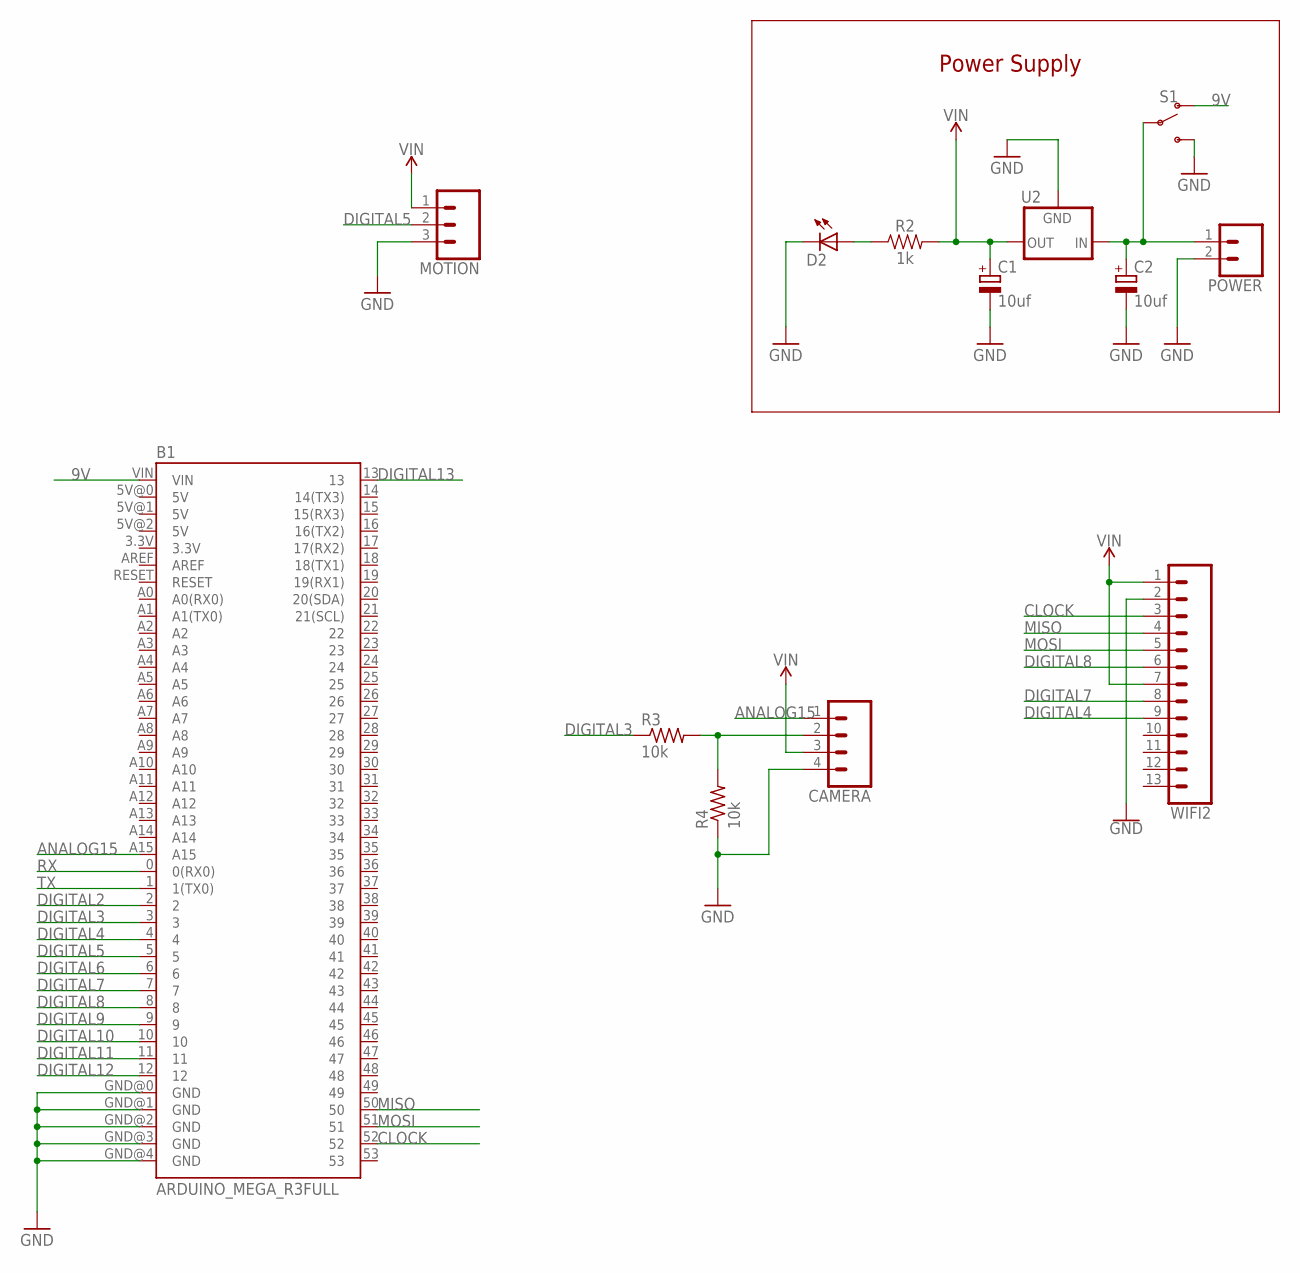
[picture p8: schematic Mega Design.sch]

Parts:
B1: ARDUINO_MEGA_R3FULL; ARDUINO_MEGA
C1, C2: 10uf; E2,5-6
CAMERA: CONN_04; 1X04
D2: LED3MM
MOTION: CONN_03; 1X03
POWER: CONN_025MM; SCREWTERMINAL-5MM-2
R2: 1k; AXIAL-0.3
R3, R4: 10k; 0207/10
S1: SWITCH-SPDT-PTH-11.6X4.0MM; SWITCH_SPDT_PTH_11.6X4.0MM
U2: V_REG_78XX-TO-220; TO-220-ALT
WIFI2: CONN_13; 1X13

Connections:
9V: B1.VIN, S1.1 (O)
ANALOG15: B1.A15, CAMERA.1
CLOCK: B1.52, WIFI2.3
DIGITAL2: B1.2
DIGITAL3: B1.3, R3.1
DIGITAL4: B1.4, WIFI2.9
DIGITAL5: B1.5, MOTION.2
DIGITAL6: B1.6
DIGITAL7: B1.7, WIFI2.8
DIGITAL8: B1.8, WIFI2.6
DIGITAL9: B1.9
DIGITAL10: B1.10
DIGITAL11: B1.11
DIGITAL12: B1.12
DIGITAL13: B1.13
GND: B1.GND@0 (GND), B1.GND@1 (GND), B1.GND@2 (GND), B1.GND@3 (GND), B1.GND@4 (GND), C1.-, C2.-, CAMERA.4, D2.K (C), MOTION.3, POWER.2, R4.1, S1.3 (S), U2.GND, WIFI2.2
MISO: B1.50, WIFI2.4
MOSI: B1.51, WIFI2.5
unnamed: C2.+, POWER.1, S1.2, U2.IN
unnamed: D2.A, R2.P$1 (1)
unnamed: CAMERA.2, R3.2, R4.2
RX: B1.0 (0(RX0))
TX: B1.1 (1(TX0))
VIN: C1.+, CAMERA.3, MOTION.1, R2.P$2 (2), U2.OUT, WIFI2.1, WIFI2.7

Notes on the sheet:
Power Supply

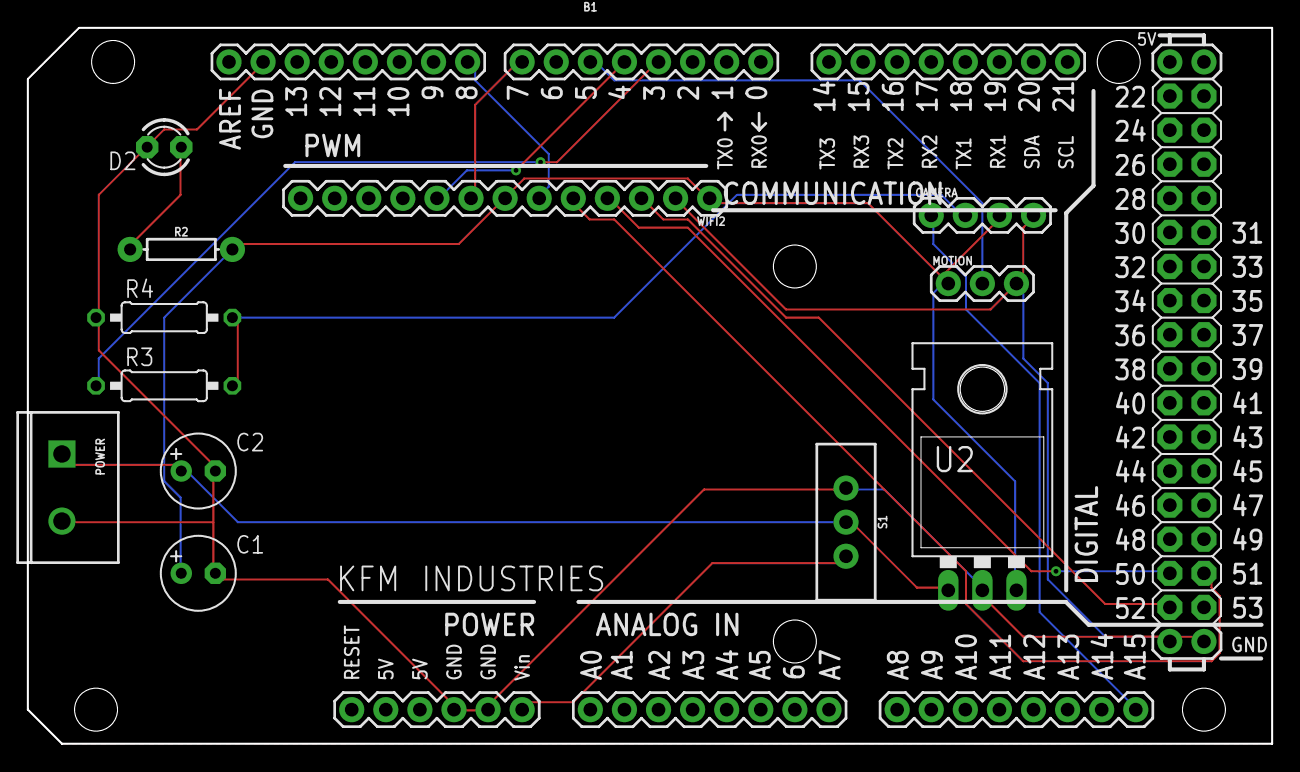
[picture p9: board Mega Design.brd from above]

Board: 2 copper layers, 92.7 x 53.3 mm, 13 parts (0 on the bottom side), 15 nets.

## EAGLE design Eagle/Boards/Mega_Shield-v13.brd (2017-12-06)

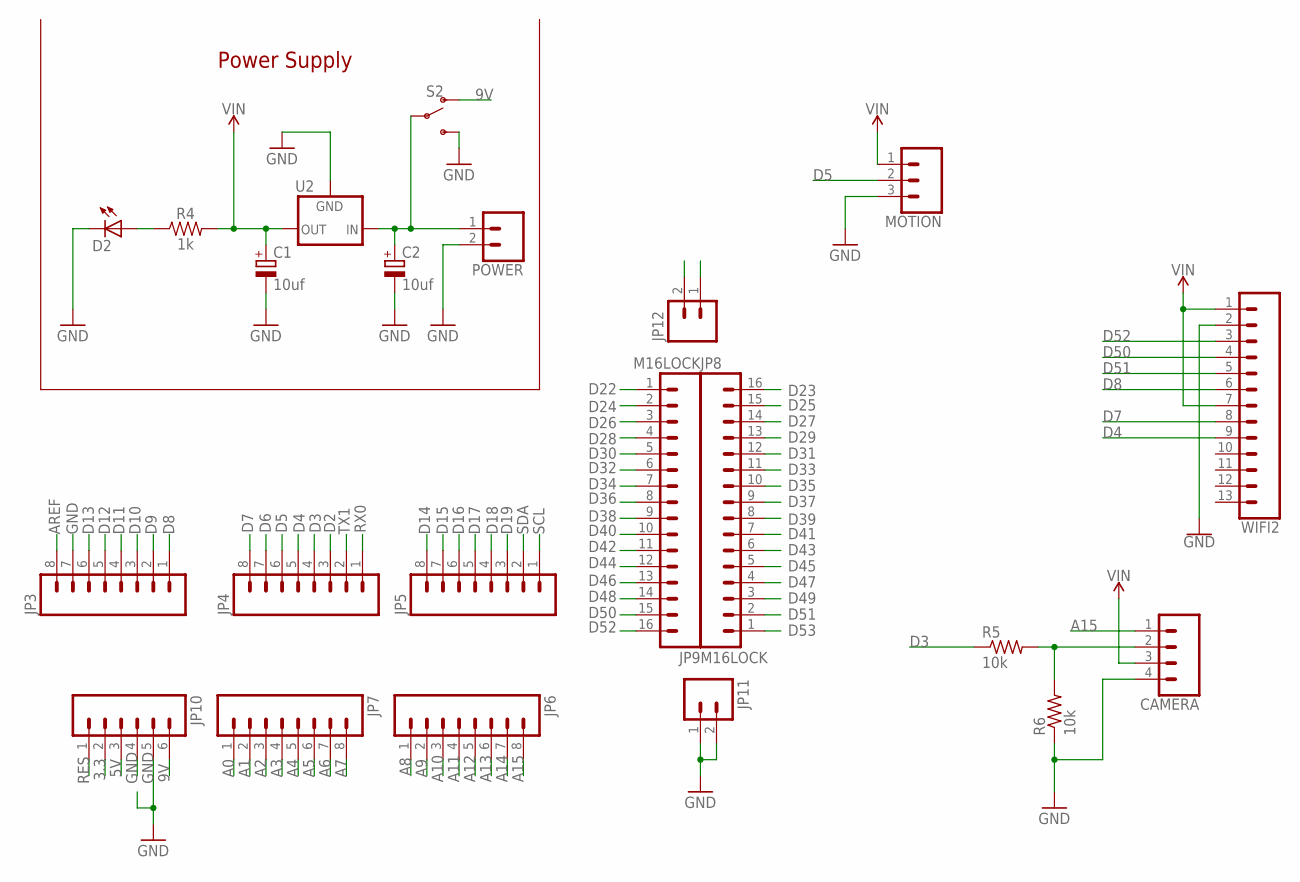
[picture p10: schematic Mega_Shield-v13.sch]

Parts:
C1, C2: 10uf; E2,5-6
CAMERA: CONN_04; 1X04
D2: LED3MM
JP3, JP4, JP5, JP6, JP7: M08LOCK; 1X08_LOCK
JP8, JP9: M16LOCK; 1X16_LOCK
JP10: M06LOCK; 1X06_LOCK
JP11, JP12: M02LOCK; 1X02_LOCK
MOTION: CONN_03; 1X03
POWER: CONN_025MM; SCREWTERMINAL-5MM-2
R4: 1k; AXIAL-0.3
R5, R6: 10k; 0207/10
S2: SWITCH-SPDT-PTH-11.6X4.0MM; SWITCH_SPDT_PTH_11.6X4.0MM
U2: V_REG_78XX-TO-220; TO-220-ALT
WIFI2: CONN_13; 1X13

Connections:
3.3: JP10.2
5V: JP10.3
5V@1: JP12.1, JP12.2
9V: JP10.6, S2.1 (O)
A0: JP7.1
A1: JP7.2
A2: JP7.3
A3: JP7.4
A4: JP7.5
A5: JP7.6
A6: JP7.7
A7: JP7.8
A8: JP6.1
A9: JP6.2
A10: JP6.3
A11: JP6.4
A12: JP6.5
A13: JP6.6
A14: JP6.7
A15: CAMERA.1, JP6.8
AREF: JP3.8
D2: JP4.3
D3: JP4.4, R5.1
D4: JP4.5, WIFI2.9
D5: JP4.6, MOTION.2
D6: JP4.7
D7: JP4.8, WIFI2.8
D8: JP3.1, WIFI2.6
D9: JP3.2
D10: JP3.3
D11: JP3.4
D12: JP3.5
D13: JP3.6
D14: JP5.8
D15: JP5.7
D16: JP5.6
D17: JP5.5
D18: JP5.4
D19: JP5.3
D22: JP9.1
D23: JP8.16
D24: JP9.2
D25: JP8.15
D26: JP9.3
D27: JP8.14
D28: JP9.4
D29: JP8.13
D30: JP9.5
D31: JP8.12
D32: JP9.6
D33: JP8.11
D34: JP9.7
D35: JP8.10
D36: JP9.8
D37: JP8.9
D38: JP9.9
D39: JP8.8
D40: JP9.10
D41: JP8.7
D42: JP9.11
D43: JP8.6
D44: JP9.12
D45: JP8.5
D46: JP9.13
D47: JP8.4
D48: JP9.14
D49: JP8.3
D50: JP9.15, WIFI2.4
D51: JP8.2, WIFI2.5
D52: JP9.16, WIFI2.3
D53: JP8.1
GND: C1.-, C2.-, CAMERA.4, D2.K (C), JP3.7, JP10.4, JP10.5, JP11.1, JP11.2, MOTION.3, POWER.2, R6.1, S2.3 (S), U2.GND, WIFI2.2
unnamed: C2.+, POWER.1, S2.2, U2.IN
unnamed: D2.A, R4.P$1 (1)
unnamed: CAMERA.2, R5.2, R6.2
RES: JP10.1
RX0: JP4.1
SCL: JP5.1
SDA: JP5.2
TX1: JP4.2
VIN: C1.+, CAMERA.3, MOTION.1, R4.P$2 (2), U2.OUT, WIFI2.1, WIFI2.7

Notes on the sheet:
Power Supply

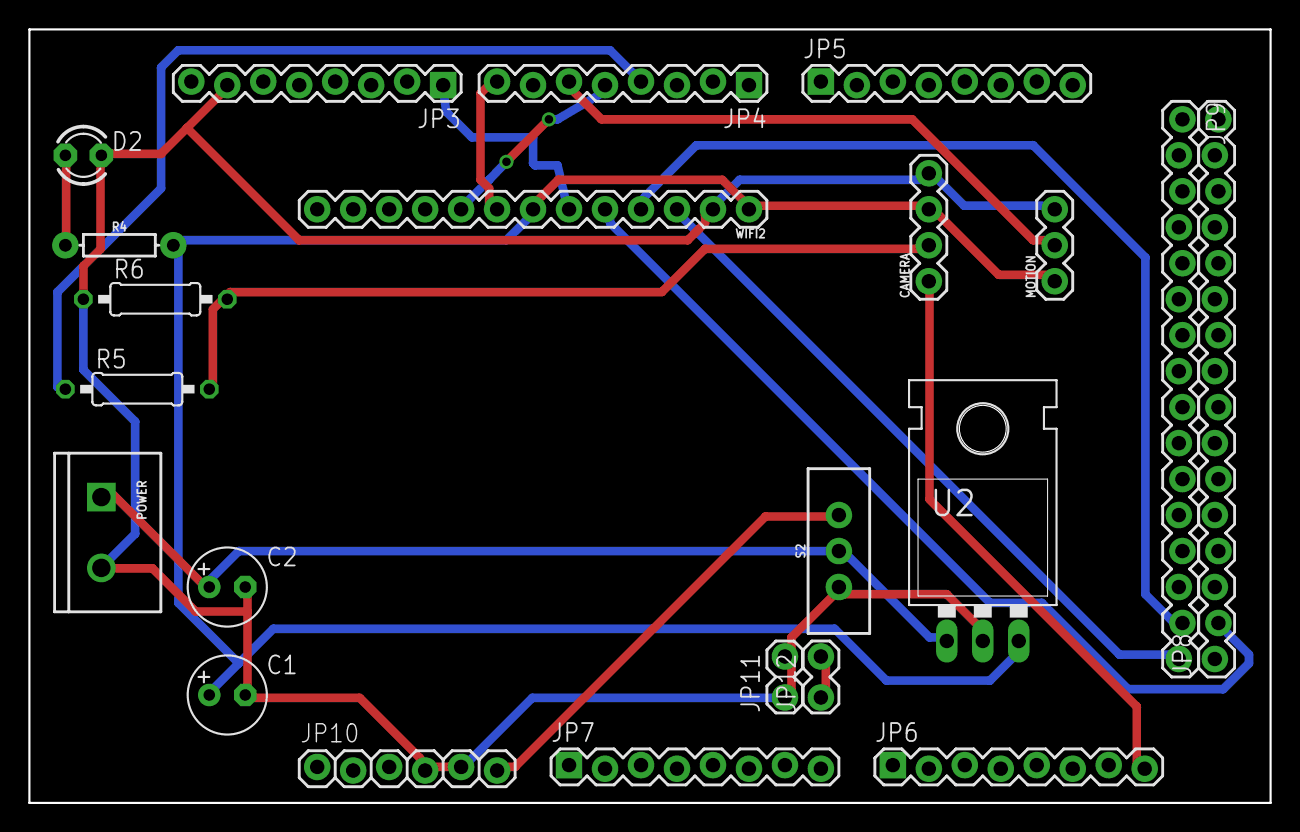
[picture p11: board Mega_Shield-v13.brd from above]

Board: 2 copper layers, 87.6 x 54.6 mm, 22 parts (0 on the bottom side), 16 nets.

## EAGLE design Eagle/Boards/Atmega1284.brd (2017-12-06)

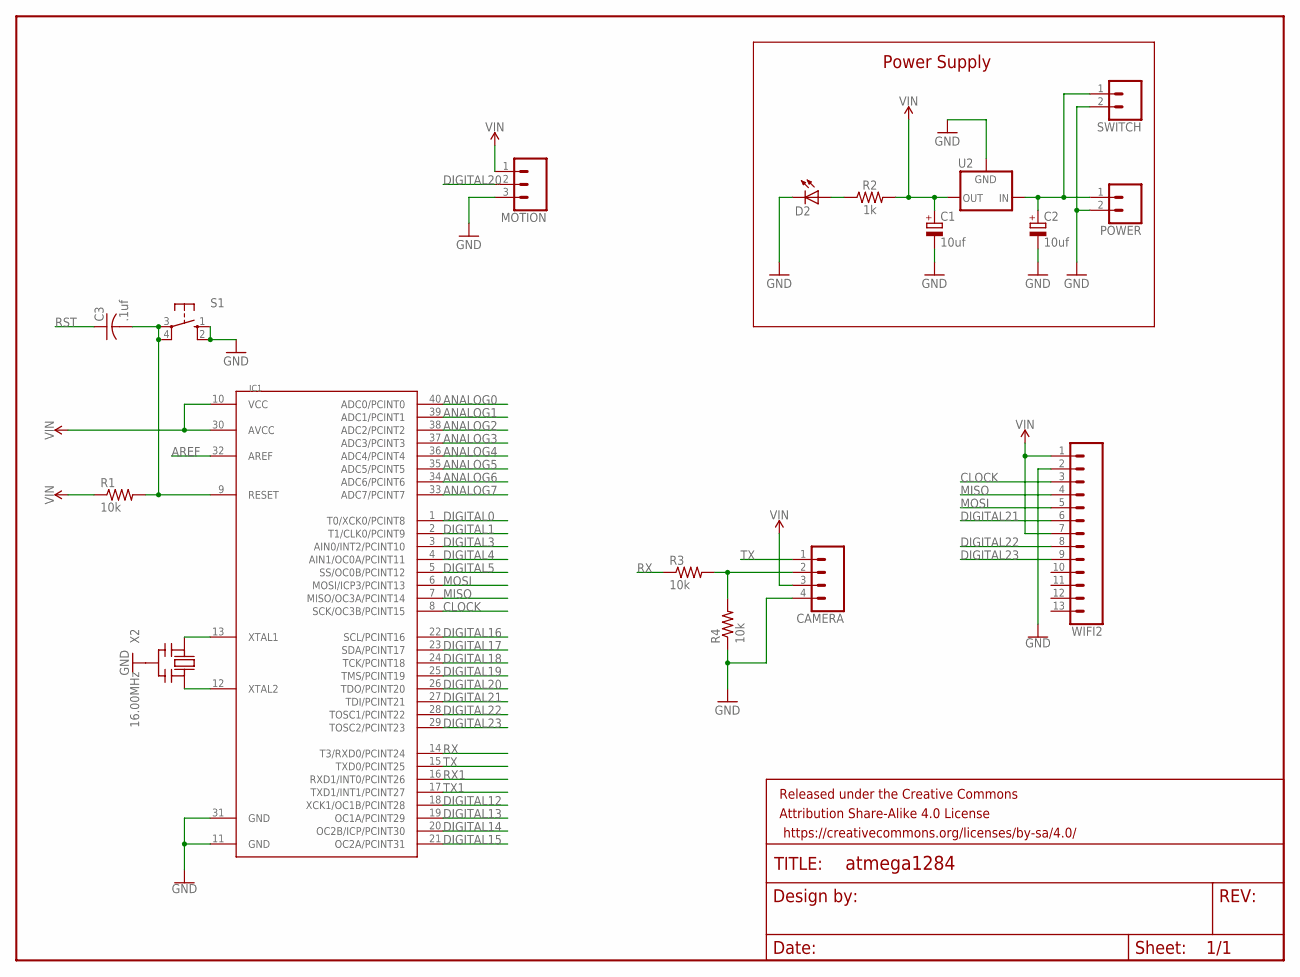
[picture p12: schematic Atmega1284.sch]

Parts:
C1, C2: 10uf; E2,5-6
C3: .1uf; C025-024X044
CAMERA: CONN_04; 1X04
D2: LED3MM
FRAME1: FRAME-LETTER; CREATIVE_COMMONS
IC1: MEGA1284P; DIL40
MOTION: CONN_03; 1X03
POWER: CONN_025MM; SCREWTERMINAL-5MM-2
R1, R3, R4: 10k; 0207/10
R2: 1k; AXIAL-0.3
S1: RESET; B3F-10XX
SWITCH: CONN_02; 1X02
U2: V_REG_78XX-TO-220; TO-220-ALT
WIFI2: CONN_13; 1X13
X2: 16.00MHz; CERM_OSC

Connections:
ANALOG0: IC1.40 (ADC0/PCINT0)
ANALOG1: IC1.39 (ADC1/PCINT1)
ANALOG2: IC1.38 (ADC2/PCINT2)
ANALOG3: IC1.37 (ADC3/PCINT3)
ANALOG4: IC1.36 (ADC4/PCINT4)
ANALOG5: IC1.35 (ADC5/PCINT5)
ANALOG6: IC1.34 (ADC6/PCINT6)
ANALOG7: IC1.33 (ADC7/PCINT7)
CLOCK: IC1.8 (SCK/OC3B/PCINT15), WIFI2.3
DIGITAL0: IC1.1 (T0/XCK0/PCINT8)
DIGITAL1: IC1.2 (T1/CLK0/PCINT9)
DIGITAL3: IC1.3 (AIN0/INT2/PCINT10)
DIGITAL4: IC1.4 (AIN1/OC0A/PCINT11)
DIGITAL5: IC1.5 (SS/OC0B/PCINT12)
DIGITAL12: IC1.18 (XCK1/OC1B/PCINT28)
DIGITAL13: IC1.19 (OC1A/PCINT29)
DIGITAL14: IC1.20 (OC2B/ICP/PCINT30)
DIGITAL15: IC1.21 (OC2A/PCINT31)
DIGITAL16: IC1.22 (SCL/PCINT16)
DIGITAL17: IC1.23 (SDA/PCINT17)
DIGITAL18: IC1.24 (TCK/PCINT18)
DIGITAL19: IC1.25 (TMS/PCINT19)
DIGITAL20: IC1.26 (TDO/PCINT20), MOTION.2
DIGITAL21: IC1.27 (TDI/PCINT21), WIFI2.6
DIGITAL22: IC1.28 (TOSC1/PCINT22), WIFI2.8
DIGITAL23: IC1.29 (TOSC2/PCINT23), WIFI2.9
GND: C1.-, C2.-, CAMERA.4, D2.K (C), IC1.11 (GND), MOTION.3, POWER.2, R4.1, S1.1 (S), S1.2 (S1), SWITCH.2, U2.GND, WIFI2.2, X2.P$2 (GND)
MISO: IC1.7 (MISO/OC3A/PCINT14), WIFI2.4
MOSI: IC1.6 (MOSI/ICP3/PCINT13), WIFI2.5
unnamed: C2.+, POWER.1, SWITCH.1, U2.IN
unnamed: D2.A, R2.P$1 (1)
unnamed: CAMERA.2, R3.2, R4.2
unnamed: IC1.13 (XTAL1), X2.P$1 (IN)
unnamed: IC1.12 (XTAL2), X2.P$3 (OUT)
RST: C3.1, C3.2, IC1.9 (RESET), R1.2, S1.3, S1.4 (P1)
RX: IC1.14 (T3/RXD0/PCINT24), R3.1
RX1: IC1.16 (RXD1/INT0/PCINT26)
TX: CAMERA.1, IC1.15 (TXD0/PCINT25)
TX1: IC1.17 (TXD1/INT1/PCINT27)
VIN: C1.+, CAMERA.3, IC1.10 (VCC), MOTION.1, R1.1, R2.P$2 (2), U2.OUT, WIFI2.1, WIFI2.7

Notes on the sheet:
Power Supply

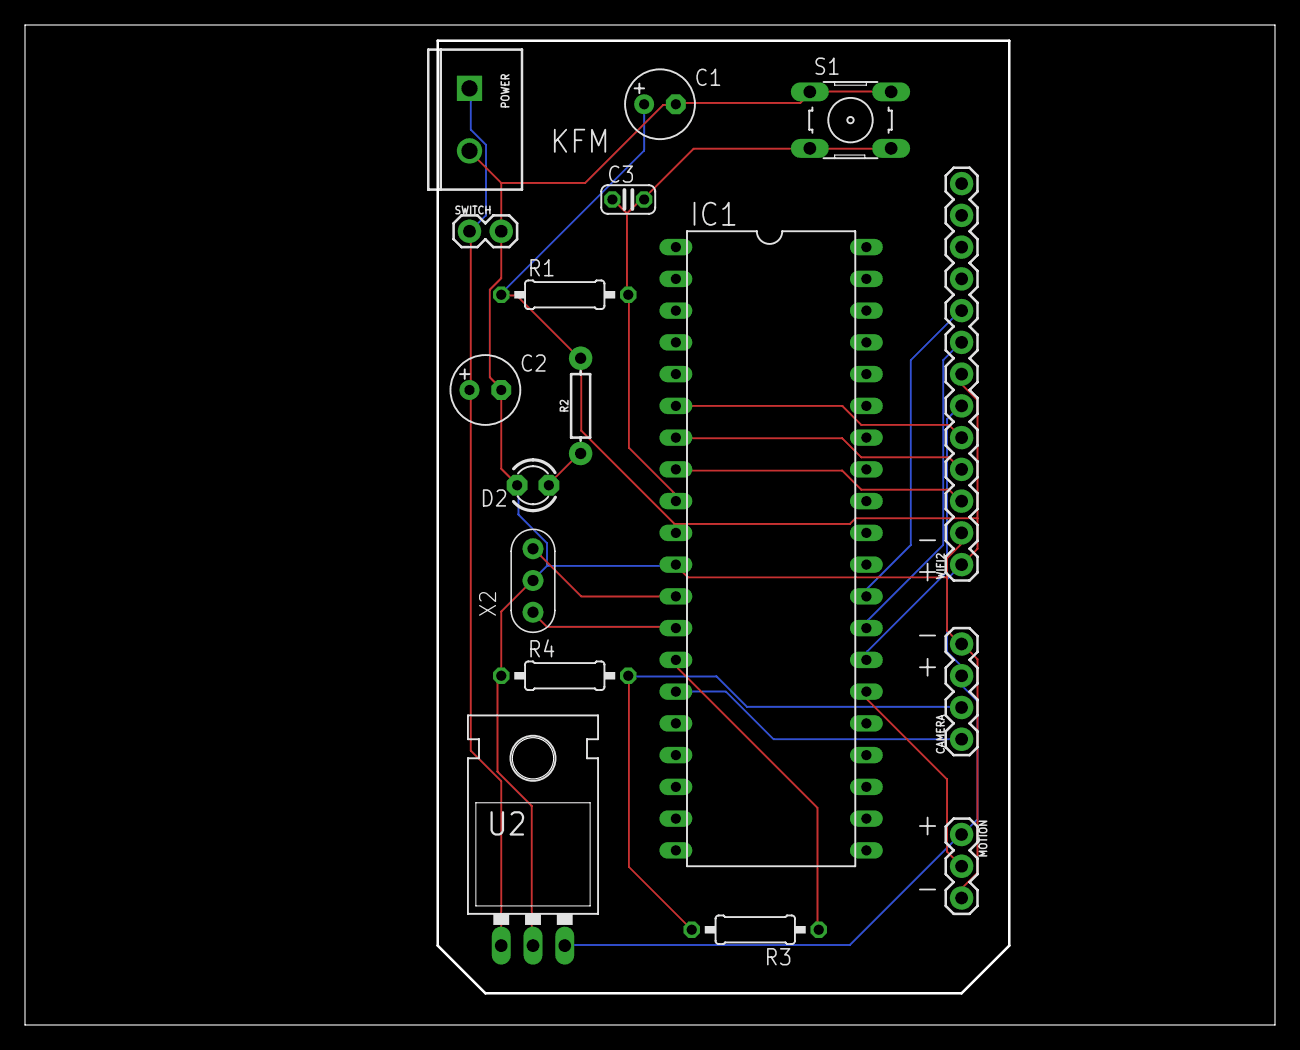
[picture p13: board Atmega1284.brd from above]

Board: 2 copper layers, 100.0 x 80.0 mm, 18 parts (0 on the bottom side), 17 nets.

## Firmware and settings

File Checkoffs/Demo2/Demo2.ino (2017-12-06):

/**
 * Demo 2 - Senior Design
 * November 2017
 * Jonathan Kenneson & Kyle Monto
 *
 * This demo showcases functionality from the motion detector, camera, and wireless chip.
 * When the motion sensor is triggered, the camera takes a picture and sends it to the Server
 * to be displayed on a webpage.
 */

#include <Adafruit_VC0706.h>
#include <SPI.h>
#include <SD.h>
#include <SoftwareSerial.h>
#include <WiFi101.h>   // changed from Wifi101.h to Wifi.h
#include <PubSubClient.h>


//*********************************************************************************//
//                             Camera Globals                                      //
//*********************************************************************************//

// On Mega: camera TX connected to pin 69 (A15), camera RX to pin 3:
SoftwareSerial cameraSerial = SoftwareSerial(69, 3);

byte incomingbyte;
int a=0x0000;  //Read Starting address
int j=0;
int k=0;
int count=0;
uint8_t MH,ML;
boolean EndFlag=0;


//*********************************************************************************//
//                           Motion Sensor Globals                                 //
//*********************************************************************************//
int pirInputPin = 5;               // choose the input pin (for PIR sensor)
int pirStatus = 0;                 // variable for reading the pin status


//*********************************************************************************//
//                               Wifi Globals                                      //
//*********************************************************************************//
WiFiClient wclient;
//char ssid[] = "FBI Van 3";        // your network SSID (name)
//char pass[] = "brightquail370";    // your network password (use for WPA, or use as key for WEP)
char ssid[] = "Embedded Systems Class";        // your network SSID (name)
char pass[] = "embedded1234";    // your network password (use for WPA, or use as key for WEP)

int status = WL_IDLE_STATUS;     // the WiFi radio's status

byte server[] = { 198, 41, 30, 241 }; //  Public MQTT Brokers: http://mqtt.org/wiki/doku.php/public_brokers
byte ip[]     = { 172, 16, 0, 100 };

void callback(char* inTopic, byte* payload, unsigned int length){
// Handle callback here

}

PubSubClient client(server, 1883, callback, wclient);



//*********************************************************************************//
//                                  Setup()                                        //
//*********************************************************************************//

void setup() {
  Serial.begin(9600);

//  Camera Setup BEGIN
  Serial.print("Camera Setup");
  cameraSerial.begin(38400);

  SendResetCmd();
  delay(2000);          //Delay for bit stabilization
  ChangeSizeMedium();
  delay(2000);
  Serial.println("... Complete!");
//  Camera setup END


// Motion Sensor Setup BEGIN
  pinMode(pirInputPin, INPUT);     // Declare sensor as input
  Serial.print("Motion Sensor Setup");
  delay(5000);
  Serial.println("... Complete!");
//  Motion Sensor Setup END


//  Wifi Setup BEGIN
  //Configure pins for Adafruit ATWINC1500 Breakout
  WiFi.setPins(8,7,4);    //WiFi.setPins(chipSelect, irq, reset, enable)  - enable tied to VCC

  // check for the presence of the shield:
  if (WiFi.status() == WL_NO_SHIELD) {
    Serial.println();
    Serial.println("WiFi shield not present. Not continuing execution.");
    // don't continue:
    while (true);
  }

  // attempt to connect to WiFi network:
  while ( status != WL_CONNECTED) {
    Serial.print("Attempting to connect to WPA SSID: ");
    Serial.println(ssid);
    // Connect to WPA/WPA2 network:
    status = WiFi.begin(ssid, pass);

    // wait 5 seconds for connection:
    delay(5000);
  }

  // Connected now, so print out the data:
  Serial.println("Connected to the network!");
  printWiFiData();
  Serial.println();
  Serial.println("Waiting for motion sensor trigger...");

  sendMessageToServer("Test");    //Send test message to establish connection
//  Wifi Setup END
}


//*********************************************************************************//
//                                  main()                                         //
//*********************************************************************************//

void loop() {
  pirStatus = digitalRead(pirInputPin);  // read input value

//  Serial.print("State: ");
//  Serial.println(pirStatus);
  if(pirStatus == HIGH){
    takePicture();
  }

}




//*********************************************************************************//
//                            Camera Main Functions                                //
//*********************************************************************************//

void takePicture() {
  char pictureArray[1024];
  memset(pictureArray, '\0', 1024);
//  delay(100);
  
  SendTakePhotoCmd();

  Serial.println("Taking picture");
  delay(100);

  while(cameraSerial.available()>0) {
    incomingbyte=cameraSerial.read();
  }
  byte b[32];
  int byteCount = 0;

  while(!EndFlag) {
    j=0;
    k=0;
    count=0;
    SendReadDataCmd();

    delay(75); //try going up
    while(cameraSerial.available()>0) {
      incomingbyte=cameraSerial.read();
      k++;
      if((k>5)&&(j<32)&&(!EndFlag)) {
        b[j]=incomingbyte;
        if((b[j-1]==0xFF)&&(b[j]==0xD9))
        EndFlag=1;
        j++;
        count++;
      }
    }

    for(j=0;j<count;j++) {
      if(b[j]<0x10)
      {
//        Serial.print("0");
        pictureArray[byteCount] = '0';
        byteCount++;
        pictureArray[byteCount] = String(b[j], HEX)[0];
        byteCount++;
      }
      else {
//        Serial.print(b[j], HEX);
        pictureArray[byteCount] = String(b[j], HEX)[0];
        byteCount++;
        pictureArray[byteCount] = String(b[j], HEX)[1];
        byteCount++;
      }

      if(byteCount > 200) {
        sendMessageToServer(pictureArray);
        memset(pictureArray, '\0', 1024);
        byteCount = 0;
//        delay(100);
      }
    }
  }


  StopTakePhotoCmd(); //stop this picture so another one can be taken
  EndFlag = 0; //reset flag to allow another picture to be read
  
  //Send last data to Server
  sendMessageToServer(pictureArray);
  sendMessageToServer("KFM");

  Serial.println("End of picture");
  Serial.println();

  delay(5000);
}


//*********************************************************************************//
//                           Wifi Main Functions                                   //
//*********************************************************************************//


void sendMessageToServer(char pictureArray []){
// convert into to char array
//  int str_len = stringBuild.length() + 1;  // Length (with one extra character for the null terminator)
//  char char_array[str_len];  // Prepare the character array (the buffer)
//  stringBuild.toCharArray(char_array, str_len);  // Copy it over


//  Serial.println();
  Serial.print("Attempting to publish: ");
  Serial.println(pictureArray);

  bool published = false;
  // publish data to MQTT broker
  while(!published) {
    if (client.connect("LaunchPadClient", "KFM", 2, 1, "Hello World")) {
      if(client.publish("KFM", pictureArray) == true) {
//        Serial.println("Publishing successful!");
        published = true;
      }
      else {
//        Serial.println("Publishing unsuccessful :(");
          delay(250);
      }
      client.disconnect();
    }
  }
  
}




//*********************************************************************************//
//                          Camera Helper Functions                                //
//*********************************************************************************//

//Send Reset command
void SendResetCmd() {
  cameraSerial.write((byte)0x56);
  cameraSerial.write((byte)0x00);
  cameraSerial.write((byte)0x26);
  cameraSerial.write((byte)0x00);
}

//Send take picture command
void SendTakePhotoCmd() {
  cameraSerial.write((byte)0x56);
  cameraSerial.write((byte)0x00);
  cameraSerial.write((byte)0x36);
  cameraSerial.write((byte)0x01);
  cameraSerial.write((byte)0x00);

  a = 0x0000; //reset so that another picture can taken
}

void FrameSize() {
  cameraSerial.write((byte)0x56);
  cameraSerial.write((byte)0x00);
  cameraSerial.write((byte)0x34);
  cameraSerial.write((byte)0x01);
  cameraSerial.write((byte)0x00);
}

//Read data
void SendReadDataCmd() {
  MH=a/0x100;
  ML=a%0x100;

  cameraSerial.write((byte)0x56);
  cameraSerial.write((byte)0x00);
  cameraSerial.write((byte)0x32);
  cameraSerial.write((byte)0x0c);
  cameraSerial.write((byte)0x00);
  cameraSerial.write((byte)0x0a);
  cameraSerial.write((byte)0x00);
  cameraSerial.write((byte)0x00);
  cameraSerial.write((byte)MH);
  cameraSerial.write((byte)ML);
  cameraSerial.write((byte)0x00);
  cameraSerial.write((byte)0x00);
  cameraSerial.write((byte)0x00);
  cameraSerial.write((byte)0x20);
  cameraSerial.write((byte)0x00);
  cameraSerial.write((byte)0x0a);

  a+=0x20;
}

void StopTakePhotoCmd() {
  cameraSerial.write((byte)0x56);
  cameraSerial.write((byte)0x00);
  cameraSerial.write((byte)0x36);
  cameraSerial.write((byte)0x01);
  cameraSerial.write((byte)0x03);
}

//160*120
void ChangeSizeSmall() {
    cameraSerial.write((byte)0x56);
    cameraSerial.write((byte)0x00);
    cameraSerial.write((byte)0x31);
    cameraSerial.write((byte)0x05);
    cameraSerial.write((byte)0x04);
    cameraSerial.write((byte)0x01);
    cameraSerial.write((byte)0x00);
    cameraSerial.write((byte)0x19);
    cameraSerial.write((byte)0x22);
}

//320*240
void ChangeSizeMedium()
{
    cameraSerial.write((byte)0x56);
    cameraSerial.write((byte)0x00);
    cameraSerial.write((byte)0x31);
    cameraSerial.write((byte)0x05);
    cameraSerial.write((byte)0x04);
    cameraSerial.write((byte)0x01);
    cameraSerial.write((byte)0x00);
    cameraSerial.write((byte)0x19);
    cameraSerial.write((byte)0x11);
}

//640*480
void ChangeSizeBig()
{
    cameraSerial.write((byte)0x56);
    cameraSerial.write((byte)0x00);
    cameraSerial.write((byte)0x31);
    cameraSerial.write((byte)0x05);
    cameraSerial.write((byte)0x04);
    cameraSerial.write((byte)0x01);
    cameraSerial.write((byte)0x00);
    cameraSerial.write((byte)0x19);
    cameraSerial.write((byte)0x00);
}


//*********************************************************************************//
//                          Wifi Helper Functions                                  //
//*********************************************************************************//

void printWiFiData() {
  // print your WiFi shield's IP address:
  IPAddress ip = WiFi.localIP();
  Serial.print("\tIP address : ");
  Serial.println(ip);

  Serial.print("\tSubnet mask: ");
  Serial.println((IPAddress)WiFi.subnetMask());

  Serial.print("\tGateway IP : ");
  Serial.println((IPAddress)WiFi.gatewayIP());

  // print your MAC address:
  byte mac[6];
  WiFi.macAddress(mac);
  Serial.print("\tMAC address: ");
  Serial.print(mac[5], HEX);
  Serial.print(":");
  Serial.print(mac[4], HEX);
  Serial.print(":");
  Serial.print(mac[3], HEX);
  Serial.print(":");
  Serial.print(mac[2], HEX);
  Serial.print(":");
  Serial.print(mac[1], HEX);
  Serial.print(":");
  Serial.println(mac[0], HEX);
  Serial.println();
}

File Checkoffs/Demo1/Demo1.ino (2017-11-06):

//Wifi101 library conflicts with Software Serial library (possibly using interrupts on the same pins)
//Need to either figure out how to use Wifi.h library or switch to Mega

#include <Adafruit_VC0706.h>
#include <SPI.h>
#include <SD.h>
#include <SoftwareSerial.h>
#include <WiFi101.h>   // changed from Wifi101.h to Wifi.h
#include <PubSubClient.h> 


// On Mega: camera TX connected to pin 69 (A15), camera RX to pin 3:
SoftwareSerial cameraconnection = SoftwareSerial(69, 3);
// On Uno: Tx to pin 2, Rx to pin 3
//SoftwareSerial cameraconnection = SoftwareSerial(2, 3);
Adafruit_VC0706 cam = Adafruit_VC0706(&cameraconnection);

//PIR motion sensor globals
int pirInputPin = 5;               // choose the input pin (for PIR sensor)
int pirState = LOW;             // we start, assuming no motion detected
int pirStatus = 0;                    // variable for reading the pin status

//Wifi globals
WiFiClient wclient;
//char ssid[] = "FBI Van 3";        // your network SSID (name)
//char pass[] = "brightquail370";    // your network password (use for WPA, or use as key for WEP)
char ssid[] = "Embedded Systems Class";        // your network SSID (name)
char pass[] = "embedded1234";    // your network password (use for WPA, or use as key for WEP)

int status = WL_IDLE_STATUS;     // the WiFi radio's status

byte server[] = { 198, 41, 30, 241 }; //  Public MQTT Brokers: http://mqtt.org/wiki/doku.php/public_brokers
byte ip[]     = { 172, 16, 0, 100 };

void callback(char* inTopic, byte* payload, unsigned int length){
// Handle callback here

}

PubSubClient client(server, 1883, callback, wclient);

void setup() {
  Serial.begin(9600);

//  Camera Setup BEGIN

  Serial.println("KFM Demo 1");
  
  // Try to locate the camera
  if (cam.begin()) {
    Serial.println("Camera Found:");
  } else {
    Serial.println("No camera found?");
    return;
  }
  // Print out the camera version information (optional)
  char *reply = cam.getVersion();
  if (reply == 0) {
    Serial.print("Failed to get version");
  } else {
    Serial.println("-----------------");
    Serial.print(reply);
    Serial.println("-----------------");
  }

  // Set the picture size - you can choose one of 640x480, 320x240 or 160x120 
  // Remember that bigger pictures take longer to transmit!
  
  cam.setImageSize(VC0706_640x480);        // biggest
  //cam.setImageSize(VC0706_320x240);        // medium
  //cam.setImageSize(VC0706_160x120);          // small

  // You can read the size back from the camera (optional, but maybe useful?)
  uint8_t imgsize = cam.getImageSize();
  Serial.print("Image size: ");
  if (imgsize == VC0706_640x480) Serial.println("640x480");
  if (imgsize == VC0706_320x240) Serial.println("320x240");
  if (imgsize == VC0706_160x120) Serial.println("160x120");

//  Camera setup END

// Motion Sensor Setup BEGIN

  pinMode(pirInputPin, INPUT);     // declare sensor as input
  Serial.println("Motion Sensor Stabilizing...");
  delay(5000);
  Serial.println("Motion Sensor Stabilized");
//  Motion Sensor Setup END

//  Wifi Setup BEGIN
  //Configure pins for Adafruit ATWINC1500 Breakout
  WiFi.setPins(8,7,4);    //WiFi.setPins(chipSelect, irq, reset, enable)  - enable tied to VCC

  Serial.print("Wifi status: ");

  Serial.println(WiFi.status());
  // check for the presence of the shield:
  if (WiFi.status() == WL_NO_SHIELD) {
    Serial.println("WiFi shield not present");
    // don't continue:
    while (true);
  }

  // attempt to connect to WiFi network:
  while ( status != WL_CONNECTED) {
    Serial.print("Attempting to connect to WPA SSID: ");
    Serial.println(ssid);
    // Connect to WPA/WPA2 network:
    status = WiFi.begin(ssid, pass);

    // wait 5 seconds for connection:
    delay(5000);
  }

  // you're connected now, so print out the data:
  Serial.println("You're connected to the network");
//  printCurrentNet();
  printWiFiData();
//  Wifi Setup END

  
}

void loop() {
  pirStatus = digitalRead(pirInputPin);  // read input value
  
//  Serial.print("State: ");
//  Serial.println(pirStatus);
  if(pirStatus == HIGH){
    takePicture();
    sendMessageToServer("Hello, World");
  }


}

void takePicture(){
  if (! cam.takePicture()) 
    Serial.println("Failed to snap!");
  else 
    Serial.println("Picture taken!");
  
  // Get the size of the image (frame) taken  
  uint16_t jpglen = cam.frameLength();
  Serial.print("Printing ");
  Serial.print(jpglen, DEC);
  Serial.println(" byte image.");

  int32_t time = millis();
  // Read all the data up to # bytes!
  while (jpglen > 0) {
    // read 32 bytes at a time;
    uint8_t *buffer;
    uint8_t bytesToRead = min(32, jpglen); // change 32 to 64 for a speedup but may not work with all setups!
    buffer = cam.readPicture(bytesToRead);
    String str = (char*) buffer;
    
    Serial.print(str);
    //Serial.print("Read ");  Serial.print(bytesToRead, DEC); Serial.println(" bytes");
    jpglen -= bytesToRead;
  }

  time = millis() - time;
  Serial.println("done!");
  Serial.print(time); Serial.println(" ms elapsed");
}

void sendMessageToServer(String stringBuild){
  // convert into to char array
  int str_len = stringBuild.length() + 1;  // Length (with one extra character for the null terminator)
  char char_array[str_len];  // Prepare the character array (the buffer) 
  stringBuild.toCharArray(char_array, str_len);  // Copy it over 

  
  // publish data to MQTT broker
  if (client.connect("LaunchPadClient")) {
    client.publish("outTopicKMonto", char_array);
//    client.subscribe("inTopicKMonto");
    Serial.println("Publishing successful!");
    client.disconnect();
  }
  //every 5 seconds
  delay(5000);
}

void printWiFiData() {
  // print your WiFi shield's IP address:
  IPAddress ip = WiFi.localIP();
  Serial.print("IP address : ");
  Serial.println(ip);

  Serial.print("Subnet mask: ");
  Serial.println((IPAddress)WiFi.subnetMask());

  Serial.print("Gateway IP : ");
  Serial.println((IPAddress)WiFi.gatewayIP());

  // print your MAC address:
  byte mac[6];
  WiFi.macAddress(mac);
  Serial.print("MAC address: ");
  Serial.print(mac[5], HEX);
  Serial.print(":");
  Serial.print(mac[4], HEX);
  Serial.print(":");
  Serial.print(mac[3], HEX);
  Serial.print(":");
  Serial.print(mac[2], HEX);
  Serial.print(":");
  Serial.print(mac[1], HEX);
  Serial.print(":");
  Serial.println(mac[0], HEX);
  Serial.println();
}

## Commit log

2017-10-11 Dump of Test code for camera
    test camera code dump
2017-10-11 Camera Test
2017-10-20 Created Demo1
    Demo 1 created for test using motion sensor and camera. Use
    TransmissionTest for transmission demo
2017-10-20 Addition of Camera Wiring reference
    Camera picture
2017-11-06 Demo2 working with Arduino Mega
2017-11-06 Camera Print to Serial as Hex
2017-11-09 Complete picture sent to server (sometimes lost packets in transmission)
    Must look into how to fix dropped packets. However, it is now time for dinner
    [Demo2.ino]
2017-11-14 Updated Main Flow of Node Red
    Updating Main Flow of Node Red to prep for transfer over to new IBM
    Bluemix account
2017-11-17 Updated Main Flow - continuous flow
    No longer need to click link to evaluated image all done on upload,
    updated query and displays image details and email now in html format
2017-12-02 Updated Node-RED flow and added READMEs
    READMEs added to Bluemix and libraries directory
2017-12-06 Added Board and Housing Files, updated README
    [Atmega1284.brd, Atmega1284.sch, Bottom_KFM.SLDPRT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]
2017-12-08 Addition of V2 top design
    [top_KFM-v2.SLDPRT, top_KFM-v2.STL]

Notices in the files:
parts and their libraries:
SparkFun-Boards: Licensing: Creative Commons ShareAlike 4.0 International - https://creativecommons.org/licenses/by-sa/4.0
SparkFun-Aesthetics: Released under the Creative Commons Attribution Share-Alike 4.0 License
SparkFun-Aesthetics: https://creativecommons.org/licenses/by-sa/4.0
